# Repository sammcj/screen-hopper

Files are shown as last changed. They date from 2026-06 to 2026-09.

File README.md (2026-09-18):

# Screen Hopper: a smart KVM switch

This is a USB input switcher that lets you use you mouse and keyboard with two computers by just dragging the mouse cursor from one screen to the other. It's like Logitech Flow, Mouse without Borders, Synergy or Apple Universal Control, but it works entirely in hardware. No special software is required on the computers. It works with Windows, Linux and Mac.

Here's a [demo video](https://www.youtube.com/watch?v=z24jG9Nh5gk).

This project is derived from [HID Remapper](https://github.com/jfedor2/hid-remapper) so it inherits all the nice features like input remapping, sensitivity adjustment, polling rate overclocking and more. Check out that project's documentation to see its full potential.

Screen shapes and their relative position are configurable [through a web browser](https://www.jfedor.org/screen-hopper-config/) using WebHID (Chrome or Chrome-based browser required).

In addition to dragging the cursor from one screen to the other, you can also map a key or button to switch between screens.

Wireless receivers are supported and multiple devices can be connected at the same time using a USB hub.

## Profiles

Pico A stores up to 4 independent profiles. Each profile has its own screens, mappings, sensitivity, edge-resistance and jiggler interval - nothing is shared - so you can switch between, say, a single-monitor layout and a multi-monitor layout without re-running the configuration tool. Profiles are managed from the web tool (Profile tabs + active-profile selector) or directly in the multi-profile JSON shape (`{ "version": 8, "active_profile": 0, "profiles": [...] }`).

Bind any key or button to one of these target usages to switch profiles live:

- `0xfff30000` - cycle to the next profile
- `0xfff30001` .. `0xfff30004` - jump directly to profile 1..4

The hotkey lives inside each profile's own mappings, so include it in every profile you want to be able to leave.

## Keep-awake jiggler

Set a profile's `jiggle_interval` (seconds) to have Pico A nudge whichever machine has been idle longest, stopping the inactive side from locking while you work on the other. Idleness is tracked per output, so using one machine doesn't reset the other's clock.

Bind any source to target usage `0xfff30010` for a runtime on/off toggle - the onboard LED blinks **3 times for ON, 5 times for OFF**. The toggle does not change the persisted interval; it only enables/disables the jiggler for the current power cycle. When the toggle turns the jiggler ON, the cursor on the forwarder machine does a brief down/up/right/left sweep (~250 px each way, returning to where it started) so you can see the toggle landed without looking at the LED.

## Pointer upsampling (experimental)

A 125 Hz mouse (MX Master and similar) hands Pico A one position every 8 ms while the local Mac polls at 1 kHz. With no button held, Pico A walks each new sample out linearly over the following 8 ms in 1 ms steps, so the host sees ~1 kHz updates instead of 8 ms hops. This trades one sample interval of pointer latency for a smoother cursor on 60 Hz displays. Local machine only; drags and everything relative are untouched. On by default. Bind a source to `0xfff30011` to toggle it at runtime (3 blinks on, 5 off). Not persisted.

## Type text from the clipboard

`config-tool/type_text.py` ships a small CLI that turns text on the Pico-A computer into keystrokes on the forwarder machine, useful for passing a URL, a code snippet or a short password across without needing networking or host software on the second computer.

```shell
pbpaste | python3 config-tool/type_text.py    # macOS clipboard
python3 config-tool/type_text.py < file.txt   # from a file
python3 config-tool/type_text.py              # falls back to pbpaste on macOS
```

To fire it from anywhere with a hotkey, bind a shortcut in a tool like BetterTouchTool to
an "Execute Shell Script" action running `pbpaste | python3 config-tool/type_text.py`. Use
absolute paths (the script's Python and `pbpaste`), because such tools run scripts in a
minimal shell without your normal `PATH`, and pipe `pbpaste` in explicitly rather than
relying on the clipboard fallback.

The text is buffered on Pico A (cap: 4096 bytes - longer input is truncated) and replayed at ~70 characters/second through the forwarder's USB HID keyboard interface. Bytes outside printable US-ASCII (plus tab and newline) are dropped by the firmware, so the CLI transliterates non-ASCII first: box drawing becomes `+-|`, smart quotes and dashes become their ASCII forms, accents are stripped (`café` -> `cafe`), symbols get spelled out (`©` -> `(c)`, `½` -> `1/2`, `⌘` -> `cmd`), and ANSI colour escapes plus stray control bytes are removed. Characters with no ASCII form at all (emoji, CJK, Greek) are dropped and listed as a warning. Pass `--raw` to send the bytes untouched; anything still unsupported is listed and the CLI exits unless you pass `--force`. The remote machine must be on a US keyboard layout for punctuation to land correctly; letters and digits are layout-independent.

Screen hopper dual Pico version

## How is it possible?

As you might know, normal mice only send relative inputs (X/Y deltas) to the computer, they don't know where the cursor is on the screen. Screen Hopper needs to know this to be able to switch between the screens. So what it does is it keeps an internal state of where the cursor is based on the inputs received from the mouse and it sends the absolute X/Y position to the connected computers. It is a standard feature of the USB HID protocol, but normally it's only used by devices like touchscreens and graphic tablets.

There are some consequences to this mode of operation, for example the aspect ratios of the screens used need to be configured for Screen Hopper to be able to properly scale the horizontal and vertical inputs. Also it probably won't work very well with games that expect raw mouse inputs.

## How to make the device

There are two hardware versions of the Screen Hopper: the dual Pico version and the triple Pico version. They have the same functionality, but the triple Pico version has better device compatibility - some input devices work with either, but some will only work with the triple Pico version.

See [HARDWARE.md](HARDWARE.md) for details on how to make both versions of the device.

## How to use the configuration tool

A live version of the web configuration tool can be found [here](https://www.jfedor.org/screen-hopper-config/). It only works in Chrome and Chrome-based browsers. On Linux you might need to give yourself permissions to the appropriate `/dev/hidraw*` device. The configuration tool should be used on the computer connected to the Pico running `screenhopper.uf2` or `screenhopper_a.uf2`.

Some of the configuration options are inherited from [HID Remapper](https://github.com/jfedor2/hid-remapper) so check that project for the meaning of those settings (the mapping functionality can do really awesome things!).

Screen Hopper needs to know the screen shapes and their relative position to be able to move the cursor between the two computers. You configure that by entering the position (X, Y) and dimensions (width, height) of each screen. (A graphical preview would be nice here, but for now it's just numbers.) The dimensions use abstract units so their absolute values don't mean much, but you will find some combinations give you reasonable mouse sensitivity. You can adjust the sensitivity for each screen separately.

The "Restrict cursor" setting determines what should happen when you drag the mouse cursor outside of the screens (to the area that's not visible). If you select the "to screens" option, it will not be possible to go outside the visible area. If you select the "to bounding box" option, the cursor will be restricted to the smallest rectangle that covers both screens (this only makes a difference if the touching edges of the two screens are not the same length). If you select "don't restrict", the cursor will not stop at any of the screen edges.

Screens configuration

Depending on the screens configuration and the "Restrict cursor" setting, it might be possible for the cursor to be outside of the visible area. There's a separate setting for mouse sensitivity for that situation.

If you configure the screens so that they don't touch each other (there's a gap) and select the "restrict to screens" option then it will not be possible to drag the cursor from one screen to the other. You can still switch between the screens by mapping some key or button to "Switch screen".

If you can't use the browser-based configuration tool, there's also a [command-line tool](config-tool) that takes JSON in the same format as the web tool on standard input. I only tested it on Linux, but in theory it should also run on Windows and Mac.

## How to compile the firmware

Both Raspberry Pi Pico (RP2040) and Pico 2 (RP2350) are supported.

```shell
git clone https://github.com/jfedor2/screen-hopper.git
cd screen-hopper/firmware

# for pico v1:
make pico1

# for pico v2:
make pico2
```

### Firmware output

After building, the UF2 firmware files are copied to `firmware/pico1/` or `firmware/pico2/`:

| File | Version | Purpose |
| --- | --- | --- |
| `screenhopper.uf2` | Dual | Main Pico (with PIO-USB) |
| `forwarder.uf2` | Dual | Second Pico |
| `screenhopper_a.uf2` | Triple  | Pico A |
| `screenhopper_b.uf2` | Triple  | Pico B (USB host) |

To flash, hold BOOTSEL while plugging in the Pico, then copy the appropriate UF2 file to the drive that appears. Alternatively, `make flash TARGET=<a|b|forwarder|single> [BOARD=pico1|pico2] [CONFIG=path]` wraps the whole thing - it builds (re-baking if `CONFIG=` is given), auto-detects the BOOTSEL volume and uses `picotool load -x` to flash and reboot, or falls back to a Raspberry Pi Debug Probe over SWD when no BOOTSEL device is present.

### Applying config changes without reflashing

For config-only edits (screens, mappings, profiles, jiggler interval, edge resistance) reach for `make apply-config CONFIG=path/to/config.json` instead of `make flash`. It pushes the JSON to the running Pico A over USB HID (live + persisted, no reboot) and also re-bakes `firmware/src/baked_config.h` so the next `make flash` carries the same default. Only Pico A holds screen/mapping config, so config changes never need Pico B or the forwarder reflashed. Verify what the firmware is actually running with `make get-config`.

### Baking a config into the firmware

Flashing a Pico does NOT erase the persisted config sector (it lives outside the UF2 image), but if a board has no persisted config yet, the firmware uses its baked default. Bake one in as a compile-time default by passing `CONFIG` to the build:

```shell
make pico2 CONFIG=../config-tool/config.json
```

The build runs `config-tool/bake_config.py`, which turns the JSON into the same flash-sector image the device would persist, and embeds it in `firmware/src/baked_config.h`. On boot, a config persisted over USB still wins; the baked config is the fallback used when flash holds none (so a freshly flashed board comes up configured without running the configuration tool). The JSON can be a legacy single-profile shape or the multi-profile shape (`{ "version": 8, "active_profile": 0, "profiles": [...] }`).

`CONFIG` is sticky: once baked, plain `make pico2` keeps it across rebuilds. To clear it, build with an empty value, `make bake CONFIG=`. The generated `firmware/src/baked_config.h` is gitignored, so a baked personal config is never committed. A build with no baked config uses the firmware's built-in defaults as before.

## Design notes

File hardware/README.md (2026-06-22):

# Screen Hopper - triple Pico 2 carrier PCB

A carrier board for the triple-Pico version of Screen Hopper. The three Raspberry Pi Pico 2 boards, a high-speed optocoupler, the two resistors, a bypass capacitor and a USB-A host port all mount on one PCB, replacing the breadboard and jumper wires described in [HARDWARE.md](../HARDWARE.md).

Four variants are provided from the same netlist:

| Variant | Folder | Size | Assembly |
| --- | --- | ---- | --- |
| Compact SMD | [`smd/`](smd/) | 92 x 82 mm | Optocoupler + passives reflowed by the fab; you mount the three Picos flat, single-sided |
| Through-hole | [`tht/`](tht/) | 112 x 106 mm | You solder everything; Picos A and Forwarder on headers |
| Double-sided | [`compact/`](compact/) | 81 x 59 mm | Smallest by area. Pico B reflows on the back under Pico A; adds a USB-C host port |
| Plug-in header | [`header/`](header/) | 54 x 60 mm | No Pico reflow - all three Picos plug into 0.1" pin-headers. No host connector (device uses Pico B's micro-USB). Fab places only the opto + 3 passives |

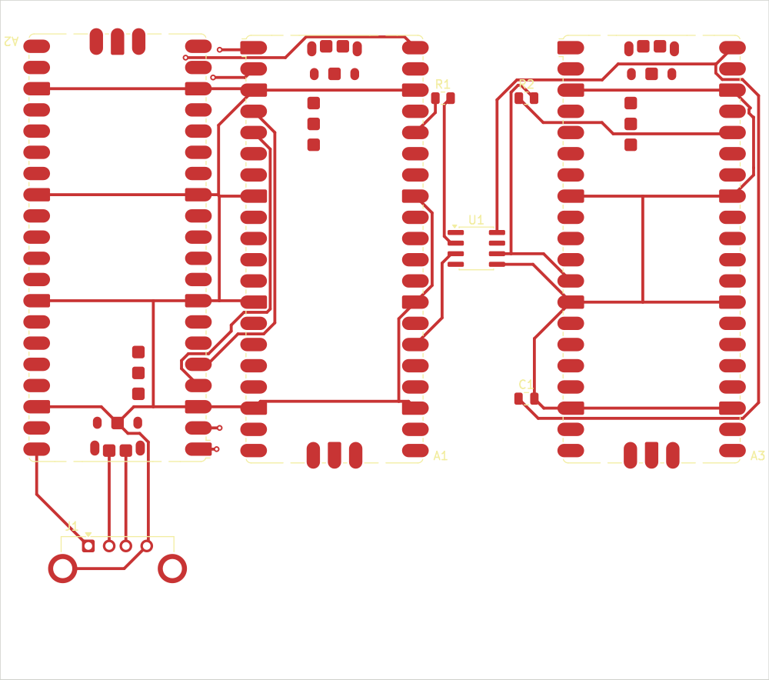
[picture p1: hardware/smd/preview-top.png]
SMD board top view


The double-sided `compact` variant is the smallest board. It stacks Pico B on the back copper directly beneath Pico A and offers both a USB-C and a USB-A host receptacle - **populate only one** (see [Host connector](#host-connector-compact-variant)). It needs the finer JLCPCB 6/6 process (0.2 mm tracks, 0.15 mm clearance, 0.5/0.3 mm vias) to fan out the 0.5 mm-pitch USB-C, where the other two run on the relaxed cheap-everywhere rules.

The `header` variant exists so you never reflow a Pico. All three Picos plug into 0.1" pin-headers (soldering a straight header strip is far easier than reflowing a castellated module), so the fab only places the SMD optocoupler and its three passives. Pico A is on the front top row and Pico B on the back directly behind it; because two through-hole Picos can't share holes, Pico B's hole grid is **offset by 8.89 mm** (half the 17.78 mm row spacing) so the grids interleave. There is no on-board host connector: the mouse/keyboard plugs into Pico B's own micro-USB through an OTG adapter (the same D-/D+/VBUS/GND lines the other variants route to a receptacle), which is what keeps this board small and simple. It uses the same fine 6/6 process as `compact` for the dense interleaved Pico holes. See [Plug-in header variant](#plug-in-header-variant).

## The one thing that matters: galvanic isolation

The optocoupler exists to keep the two host computers electrically isolated. Pico A and Pico B share power and ground fed from computer 1 (and the input device); the Forwarder runs on its own power and ground fed from computer 2. The only connection between the two sides is the optocoupler's internal LED-to-phototransistor light path.

The board enforces this with **two separate ground/power nets** (`GND1`/`VBUS1` and `GND2`/`VBUS2`) and a **copper keepout gap under the optocoupler** that no track or pour may cross. Domain 1 copper stops just left of the opto's input pins; domain 2 copper starts just right of its output pins. Do not bridge the two sides with a wire, a ground pour, or a mounting screw/standoff that ties the grounds together - that defeats the isolation and can create a ground loop between two separate computers.

## What to send to the PCB fab

For a **bare board** (any variant), upload the gerber zip:

- `smd/screen-hopper-smd-gerbers.zip`, `tht/screen-hopper-tht-gerbers.zip`, `compact/screen-hopper-compact-gerbers.zip` or `header/screen-hopper-header-gerbers.zip`

Fab settings: **2 layers, 1.6 mm FR-4, 1 oz copper, HASL or ENIG**. The `smd`/`tht` boards use 0.35 mm tracks, 0.2 mm clearance and 0.35 mm drills, which every fab (PCBWay, JLCPCB, etc.) handles at the cheapest tier. The `compact` board needs 0.2 mm tracks, 0.15 mm clearance and 0.3 mm drills to escape the USB-C, and the `header` board uses the same finer rules to route between its dense interleaved Pico holes - order both from **JLCPCB** (its standard 6/6 process and cheapest tier cover this).

For an **SMD board assembled** by the fab, also supply:

- `BOM-smd.csv`, `BOM-compact.csv` or `BOM-header.csv` - bill of materials
- the matching `-positions.csv` - centroid / pick-and-place file

The fab can place the optocoupler (SOIC-8), the 0805 resistors and the 0805 capacitor (and, on `compact`/`header`, the SMD USB-C receptacle, the two CC resistors and the SOT-23-6 ESD array). The three Pico 2 modules are not standard catalogue parts, so either hand-solder them onto the castellated pads yourself or consign them to the fab. On `smd`/`tht` the USB-A receptacle is a through-hole vertical part, hand-soldered. On `compact` the USB-A is a horizontal edge-mount part with SMD contacts the fab can place plus two through-hole shield posts you solder by hand for mechanical strength. The `compact` board places parts on **both sides** - tell the fab it is a double-sided assembly (Pico B is the only part on the back). On `header` the fab places only the four front-side SMD parts (opto, two resistors, bypass cap); the three Picos are 0.1" through-hole parts you fit yourself, flagged DNP in the Rev0 BOM. There is no host connector - the device plugs into Pico B's micro-USB.

## Bill of materials

See [`BOM-smd.csv`](BOM-smd.csv), [`BOM-tht.csv`](BOM-tht.csv), [`BOM-compact.csv`](BOM-compact.csv) and [`BOM-header.csv`](BOM-header.csv). Summary:

| Ref | Part | SMD | THT | Compact | Header |
| --- | ---- | --- | --- | --- | --- |
| A1, A2, A3 | Raspberry Pi Pico 2 (x3) | flat castellated mount | A/Fwd on headers, B flat | flat; B on the back under A | all on 0.1" headers; B on the back, grid offset 8.89 mm |
| U1 | High-speed optocoupler | HCPL-0601 (SO-8) | 6N137 (DIP-8 + socket) | HCPL-0601 (SO-8) | HCPL-0601 (SO-8) |
| R1 | 470 R (opto LED limit) | 0805 | axial 1/4 W | 0805 | 0805 |
| R2 | 680 R (opto VO pull-up) | 0805 | axial 1/4 W | 0805 | 0805 |
| R3, R4 | 56 k (USB-C CC pull-ups) | - | - | 0805 | - |
| C1 | 100 nF (opto bypass) | 0805 | ceramic disc | 0805 | 0805 |
| J1 | USB-A receptacle (host) | through-hole (vertical) | through-hole (vertical) | horizontal edge-mount (SMD + posts) | - |
| J2 | USB-C receptacle (host) | - | - | SMD 16-pin | - |
| U2 | USBLC6-2SC6 USB ESD array | - | - | SOT-23-6 | - |

Suggested MPNs in the CSVs are starting points - confirm against your supplier's stock.

U1 note: the **6N137 has no true SO-8 package** - its surface-mount form is a wide gull-wing DIP (~10 mm span, 2.54 mm pitch) that does not fit an SO-8 land. The SO-8 builds (smd, compact, header) use the **HCPL-0601** (Broadcom; same family, identical pinout, true SO-8; HCPL-0611 is a higher-CMR drop-in). Only the through-hole build uses a real 6N137, in a DIP-8 socket.

### Host connector (compact variant)

The `compact` board carries **both** a USB-A (`J1`) and a USB-C (`J2`) host receptacle, both horizontal edge-mount parts whose openings face the left board edge, wired to the same D+/D- lines on Pico B's native USB. **Populate and use only one** - they share the data lines, so fitting both and plugging a device into each shorts two devices together. The USB-C port is wired as a host (downstream-facing): `R3`/`R4` (56 k) pull CC1/CC2 up to VBUS to advertise default USB power to whatever plugs in. Leave `R3`/`R4` and `J2` unpopulated if you only want USB-A, or leave `J1` off if you only want USB-C.

Both connectors are commonly-stocked cheap parts: the USB-C is the HRO TYPE-C-31-M-12 (LCSC C165948, a JLCPCB basic part), and the USB-A is a standard horizontal Type-A edge-mount (TE 292303-7 footprint; any equivalent fits the same pads). KiCad 10 ships no 3D model for the exact HRO USB-C footprint, so `J2`'s model is remapped in `build_board.py` to a near-identical 16-pin USB-C (`USB_C_Receptacle_GCT_USB4105...`) purely so the 3D viewer shows a body - the pads, gerbers and pick-and-place still come from the real HRO footprint.

### Plug-in header variant

The `header` board replaces every Pico's flat castellated footprint with a pair of 1x20 0.1" through-hole headers, so you solder a straight pin-header strip (easy) instead of reflowing a 40-pad castellated module (hard). Two things make the layout work:

- **Two-row stack, back-side Pico B.** Pico A sits on the front top row, the Forwarder on the front bottom row, and Pico B on the **back** directly behind Pico A. Two through-hole Picos cannot share holes, so Pico B's hole grid is shifted **8.89 mm** (half the 17.78 mm inter-row spacing) along the board so the two grids interleave - the nearest drilled holes of A and B clear each other by ~7.9 mm. The board is 54 x 60 mm.
- **No host connector.** The mouse/keyboard plugs into **Pico B's own micro-USB** (through a micro-USB OTG / host adapter). Pico B is the USB host; its native USB (D-/D+/VBUS/GND) is on that connector, electrically the same lines the `smd`/`tht`/`compact` boards route out to a USB-A/USB-C receptacle. Dropping the on-board receptacle (and the CC pull-ups, ESD array and USB tap header it needed) is what makes this the simplest, smallest variant. Trade-off: Pico B's micro-USB is also its BOOTSEL/flashing port, so unplug the input device when you reflash Pico B.

**Mounting the Picos - Pico B must sit in a socket.** Pico B (`A2`, on the back, stacked behind Pico A) is the one part that *requires* a female 0.1" socket strip (`SKT1` in the BOM, 2 x 1x20). Solder the socket into A2's hole rows from the back and clip its tails flush on the front; Pico B's own pins then plug into the socket body and never pass through the board. This is necessary because Pico A's pins, soldered on the front, protrude ~4.4 mm out the back (6 mm pins through a 1.6 mm board) directly under Pico B's body - the socket lifts Pico B ~8.5 mm clear so A's through-pins stop ~4 mm short of it (and the two pin grids interleave 8.89 mm apart, so the pins themselves never line up either). Pico A and the Forwarder sit on the front with nothing stacked over them, so they may be soldered to plain male pin-headers or socketed for easy swapping - your choice. The PCB is identical either way: a socket reuses the same plated holes, so it has no separate footprint (which is why it does not appear in the 3D render).

Silkscreen on the board names each Pico (Pico A / Pico B (back) / Forwarder), prints the corner pin numbers (1/20/21/40) for each Pico, and carries a one-line signal legend (A<->B serial on GP0-3, opto on A.GP20 / Fwd.GP9, host = Pico B micro-USB).

The fab populates only the four SMD parts (`U1`, `R1`, `R2`, `C1`); the three Picos are flagged DNP in [`header/Rev0_BOM-screen-hopper-header.csv`](header/Rev0_BOM-screen-hopper-header.csv) since you fit them by hand. Every populated MPN in the Rev0 BOM was confirmed to return itself as an exact in-stock match in NextPCB's catalogue, so the no-review automated matcher sources them without substituting a wrong value. Ground is poured per-domain (`GND1` on the host side, `GND2` on the Forwarder side) and floods stop short of the isolation gap; a few inner GND pins the autorouter leaves stranded are tied in with explicit stitch tracks, so the board verifies at 0 unconnected.

## Schematic

Each variant ships an editable KiCad schematic alongside its board:

- `smd/screen-hopper-smd.kicad_sch`
- `tht/screen-hopper-tht.kicad_sch`
- `compact/screen-hopper-compact.kicad_sch`

Upload this `.kicad_sch` to tools that ask for one (e.g. Quilter, which uses it to group related components and assign bypass capacitors). It carries the same netlist as the board, so the connectivity matches. A rendered overview is in [`schematic.svg`](schematic.svg).

## Wiring

Authoritative net list:

| Net | Connections |
| --- | --- |
| UART0 (A<->B) | A.GPIO0-B.GPIO1, A.GPIO1-B.GPIO0, A.GPIO2-B.GPIO3, A.GPIO3-B.GPIO2 |
| VBUS1 | A.VBUS, B.VBUS, J1.VBUS (header: no J1 - VBUS1 is just A.VBUS + B.VBUS) |
| GND1 | A.GND, B.GND, J1.GND + shield, B.TP1 (header: just A.GND + B.GND) |
| Opto TX | A.3V3 - R1(470) - U1.2 (anode); U1.3 (cathode) - A.GPIO20 |
| USB host | J1.D- - B.TP2 (USB_DM); J1.D+ - B.TP3 (USB_DP). Header has no on-board host port - the device uses Pico B's own micro-USB |
| ESD (compact only) | U2.I/O1 (pins 1,6) - USB_DP; U2.I/O2 (pins 3,4) - USB_DM; U2.VBUS (5) - VBUS1; U2.GND (2) - GND1 |
| VBUS2 | Fwd.VBUS - U1.8 (VCC) - C1 |
| GND2 | Fwd.GND - U1.5 (GND) - C1 |
| Opto RX | Fwd.3V3 - R2(680) - U1.6 (VO); Fwd.GPIO9 - U1.6 (VO) |

`C1` (100 nF) bypasses the optocoupler's VCC (pin 8) to GND (pin 5) - recommended by the 6N137 datasheet. Optocoupler pin 7 (VE, enable) is left unconnected, matching the working breadboard build (the 6N137's internal pull-down on VE leaves it enabled).

Two deliberate choices, both inherited from the proven breadboard build:

- **`R1` = 470 Ω** sets the opto LED drive to roughly 3.8 mA from the 3.3 V rail. That is slightly below the 6N137's typical 5 mA recommended forward current, but it switches reliably at 1 Mbaud on the breadboard and stays well clear of the LED's 20 mA limit. If you want more margin you can drop to ~330 Ω (about 5.7 mA); leave it at 470 Ω to match the validated design.
- **ESD protection** (`U2`, compact variant only): a USBLC6-2SC6 low-capacitance TVS array sits next to the host connectors and clamps the D+/D- lines to VBUS1/GND1, shunting a static-discharge spike to ground before it reaches Pico B's USB transceiver. It's invisible during normal operation and adds negligible capacitance at full-speed HID rates. It's in domain 1 only and has no effect on the galvanic isolation. The `smd`/`tht` boards omit it (matching the original build); add equivalent protection there yourself if you want it.

## Unplaced board (for external auto-placers)

`make unplaced` writes a board per variant with every footprint loaded and the full netlist assigned, but **no placement and no routing** - the parts are parked in a column just right of an empty board outline:

- `unplaced/screen-hopper-smd-unplaced.kicad_pcb` (95 x 85 mm outline)
- `unplaced/screen-hopper-tht-unplaced.kicad_pcb` (115 x 110 mm outline)
- matching `.kicad_sch` for tools that also want the schematic

Feed one of these to an auto-placement tool, then route it (or let the tool route). Two things the tool won't know about, so check them in the result:

- **Galvanic isolation.** The placer sees `GND1`/`VBUS1` and `GND2`/`VBUS2` as distinct nets but has no reason to keep the two domains physically apart. After placement, confirm domain 2 (the Forwarder `A3`, opto output pins 5/6/8, `C1`, `R2`) sits on one side and everything else on the other, with the optocoupler straddling the boundary and a clear copper gap between - see the isolation section above. The hand-placed boards in `smd/` and `tht/` already do this.
- **Pico B orientation.** Its USB test points (TP1/2/3) must face the USB-A receptacle `J1`.

## Assembly notes

- **Pico B is always SMD-mounted flat**, even on the through-hole board. The USB-A host port wires to Pico B's native USB through its bottom test points (TP1/TP2/TP3 = USB_GND/USB_DM/USB_DP), and only the flat (castellated) footprint exposes those pads.
- **Pico B's micro-USB connector shares the same D+/D- lines as the USB-A port.** Leave Pico B's micro-USB unplugged in normal use - plug it in only to flash Pico B (BOOTSEL).
- **Flashing**: Pico A gets `screenhopper_a.uf2`, Pico B gets `screenhopper_b.uf2`, the Forwarder gets `forwarder.uf2`. Reflash by holding BOOTSEL while connecting that Pico's micro-USB to a computer. Re-upload your config to Pico A afterwards.
- **No ground pour** on `smd`/`tht`/`compact` - ground is routed as copper tracks. For lower EMI you can open the `.kicad_pcb` in KiCad, add a `GND1` zone on the left domain and a `GND2` zone on the right domain (keep them clear of the isolation gap), and refill. The `header` board already pours both domains (the two-row layout strands inner GND pins that pours plus stitch tracks tidy up).
- **No mounting holes** are placed (to avoid accidentally bridging the two ground domains through a metal standoff). Add your own in KiCad if you need them - keep any in the isolation gap non-plated, and don't let a screw or standoff connect domain-1 ground to domain-2 ground.
- **Compact variant is double-sided.** Pico A reflows on the top, Pico B on the back directly beneath it (the only back-side part). Reflow or hand-solder the back first, then the top, or have the fab do both. The USB-C host port (`J2`) and USB-A (`J1`) are mutually exclusive - see [Host connector](#host-connector-compact-variant).

## Regenerating

The boards are generated, routed and verified by scripts in [`lib/`](lib/):

```sh
cd hardware
make all      # build + autoroute + verify + export gerbers for all four variants
make check    # re-run the geometry checks on the built boards
make clean    # delete generated boards and fab files
# or build one: make smd | make tht | make compact | make header
```

Requirements: KiCad 10 (provides the bundled `pcbnew` Python module and `kicad-cli`) and a Java runtime. Download `freerouting.jar` (v2.x, from the freerouting GitHub releases) into `lib/`.

Pipeline: `build_board.py` places the parts and defines the netlist with `pcbnew`, exports a Specctra DSN, the freerouting autorouter routes it, the routes are imported back, and `kicad-cli` exports the gerbers/drill/centroid. `gen_sch.py` then writes the matching `.kicad_sch` and `check_sch.py` verifies its netlist against the same net table.

## Verification

`kicad-cli pcb drc` crashes on this macOS/KiCad 10.0.3 build (a tool bug, reproducible on an empty board), so verification runs through [`lib/check_board.py`](lib/check_board.py), which uses KiCad's own geometry engine to confirm, on every variant:

- **0 unconnected** nets (every pad reaches its net)
- **0 copper-clearance violations** - no different-net copper closer than each variant's design-rule clearance less a 0.02 mm rounding margin (so 0.18 mm for `smd`/`tht` whose rule is 0.2 mm; 0.13 mm for `compact`/`header` whose rule is 0.15 mm)
- **0 copper in the isolation gap** (domains bridged only by the optocoupler)

As a final belt-and-braces step before ordering, open the `.kicad_pcb` in KiCad and run **Inspect > Design Rules Checker** once, and eyeball the board against the wiring table above.

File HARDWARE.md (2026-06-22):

# How to make the device

There are two hardware versions of the Screen Hopper: the dual Pico version and the triple Pico version. They have the same functionality, but the triple Pico version has better device compatibility - some input devices work with either, but some will only work with the triple Pico version.

Both the Raspberry Pi Pico (RP2040) and Raspberry Pi Pico 2 (RP2350) are supported. The pinout and wiring are identical between the two boards. You can mix Pico and Pico 2 boards freely, but each board must be flashed with firmware built for its chip. See the [README](README.md) for build instructions.

The reason for multiple Picos is that we need three USB interfaces and the RP2040/RP2350 chip only has one. In the dual Pico version one of the interfaces is "bit-banged" (implemented in software) using the awesome [Pico-PIO-USB](https://github.com/sekigon-gonnoc/Pico-PIO-USB) library by [sekigon-gonnoc](https://github.com/sekigon-gonnoc).

The Picos talk to one another over serial.

To flash the Picos with the appropriate firmware (see below), hold the BOOTSEL button while connecting the Pico to the computer, then copy the right UF2 file to the "RPI-RP2" drive that shows up. You can find precompiled UF2 files in the [firmware](firmware) folder.

## Dual Pico version

This version is made using:

* two Raspberry Pi Picos (or Pico 2s)
* 6N137 optocoupler
* USB Type A female breakout board (or you could use a USB extender cable cut in half)
* 470 ohm resistor (or similar)
* 680 ohm resistor (or similar)
* breadboard, some jumper wires

Dual Pico version breadboard diagram

The pin connections are as follows.

| `screenhopper.uf2` Pico | USB port breakout |
| --- | --- |
| VBUS | VCC |
| GND | GND |
| GPIO0 | D+ |
| GPIO1 | D- |

| `screenhopper.uf2` Pico | 6N137 optocoupler | |
| --- | --- | --- |
| 3V3 | A | through 470 ohm resistor |
| GPIO20 | C | |

| `forwarder.uf2` Pico | 6N137 optocoupler | |
| --- | --- | --- |
| VBUS | VCC | |
| GND | GND | |
| 3V3 | VO | through 680 ohm resistor |
| GPIO9 | VO | |

## Triple Pico version

This is the version that's compatible with most devices. It's made using:

* three Raspberry Pi Picos (or Pico 2s)
* 6N137 optocoupler
* a USB OTG cable or adapter
* 470 ohm resistor (or similar)
* 680 ohm resistor (or similar)
* breadboard, some jumper wires

Connect your mouse/keyboard to the Pico running `screenhopper_b.uf2` via an OTG cable or adapter, and connect the other two Picos to the two computers.

Triple Pico version breadboard diagram

| `screenhopper_a.uf2` Pico | `screenhopper_b.uf2` Pico |
| --- | --- |
| VBUS | VBUS |
| GND | GND |
| GPIO0 | GPIO1 |
| GPIO1 | GPIO0 |
| GPIO2 | GPIO3 |
| GPIO3 | GPIO2 |

| `screenhopper_a.uf2` Pico | 6N137 optocoupler | |
| --- | --- | --- |
| 3V3 | A | through 470 ohm resistor |
| GPIO20 | C | |

| `forwarder.uf2` Pico | 6N137 optocoupler | |
| --- | --- | --- |
| VBUS | VCC | |
| GND | GND | |
| 3V3 | VO | through 680 ohm resistor |
| GPIO9 | VO | |

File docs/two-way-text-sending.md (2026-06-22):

# Two-way text sending (forwarder machine -> main machine)

Design notes for adding the reverse text direction. Today text flows one way only: the
main machine (Pico A) types onto the forwarder machine via `config-tool/type_text.py`.
Sending text back, so the forwarder machine can type onto the main machine, is possible
but needs a hardware change. This file records what that would take so it can be picked
up later.

## Why it doesn't work today

The Pico A to forwarder link is a single optocoupler, and an optocoupler only passes
signal one way (LED to transistor). Pico A drives the opto LED from `GPIO20` (UART1 TX)
and the forwarder reads the opto transistor on `GPIO9` (UART1 RX). Pico A only ever
configures TX on UART1 (`forwarder_serial_init` in `remapper.cc`) and the forwarder only
configures RX (`forwarder_serial_init` in `forwarder.cc`). There is no electrical path
from the forwarder back to Pico A.

The Pico A to Pico B link (`serial.cc`, UART0) is full-duplex, but Pico B is the USB host
wired to the mouse and keyboard and has no connection to the second machine, so it can't
carry anything from the forwarder side.

So the reverse direction is blocked in hardware, not firmware. No firmware-only workaround
exists, because the one optocoupler physically cannot carry data the other way.

## What it would take

### 1. Hardware: a second optocoupler (the real blocker)

Add a second optocoupler (same HCPL-0601 on the SMD variants, 6N137 on through-hole) plus
its pull-up resistor, wired the opposite way:

- A forwarder TX GPIO (for example `GPIO8`, UART1 TX) drives the new opto's LED.
- Pico A reads the new opto's transistor on a free RX-capable pin (for example `GPIO21`,
  UART1 RX), giving Pico A a full-duplex UART1 (TX on 20, RX on 21).

This keeps the galvanic isolation that is the whole reason the link is optical (see
`hardware/README.md`, "The one thing that matters"). A bare wire between the two ground
domains would defeat the isolation. The current assembled board has no spare opto
footprint, so this is a hand-wired add-on now, or a footprint in the next board revision.

### 2. Firmware

- Forwarder (`forwarder.cc`): it is a USB device on the second machine, so that machine
  pushes text to it via a HID feature or output report. Fill in `tud_hid_set_report_cb`
  (currently empty) to accept a `TYPE_TEXT`-style report, buffer it, and `serial_write()`
  it over the new reverse UART. Add a TX pin to `forwarder_serial_init` (it inits RX only
  today). `serial_write()` already exists and is direction-agnostic.
- Pico A (`remapper.cc`): init UART1 RX, `serial_read()` the reverse channel, buffer into
  a second `type_buffer`, and replay as keyboard reports to a local screen (`output == 0`).
  This mirrors the existing `service_type_text()`, which targets `find_forwarder_screen()`;
  the reverse version targets `find_local_screen()`. The keyboard-to-main-machine path
  already exists from normal operation.

### 3. Host script on the forwarder machine

A mirror of `type_text.py` that grabs the second machine's clipboard and sends it to the
forwarder over USB HID, using the same chunked `TYPE_TEXT` framing (`send_chunk` in
`type_text.py`), pointed at the forwarder's VID/PID.

## Scope and effort

The firmware and host-script work is modest and reuses the existing SLIP/CRC framing and
the type-buffer replay state machine. The gating item is the second optocoupler: until the
reverse opto is wired in, the firmware and script have nothing to carry data over.

## Alternative if it doesn't have to go through the KVM

If the goal is just getting the second machine's clipboard onto the main machine, and it
doesn't have to traverse the hardware, a network path (or a shared file/note) is far less
work than a second optocoupler plus two firmware changes. The opto path only makes sense
if the second machine is deliberately isolated and routing through the hardware is the
point.

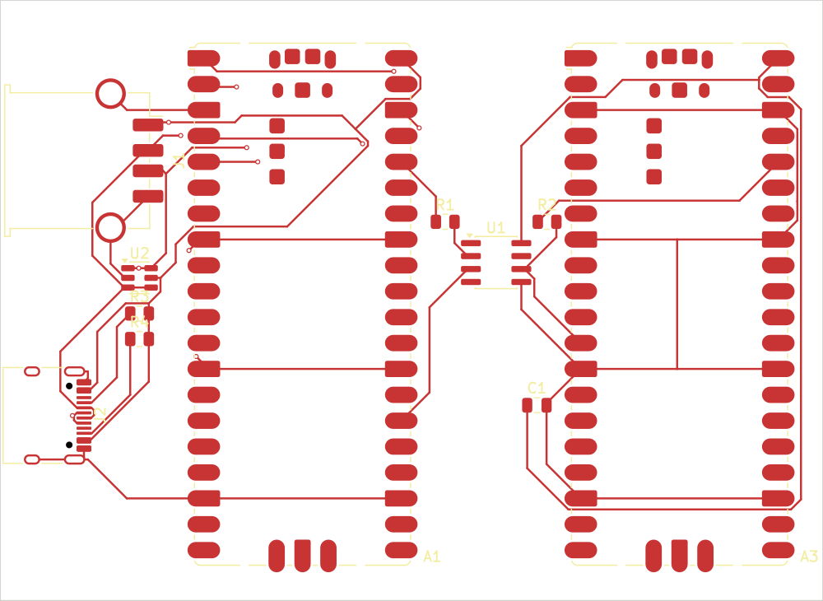
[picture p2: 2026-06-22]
hardware/compact/preview-top.png

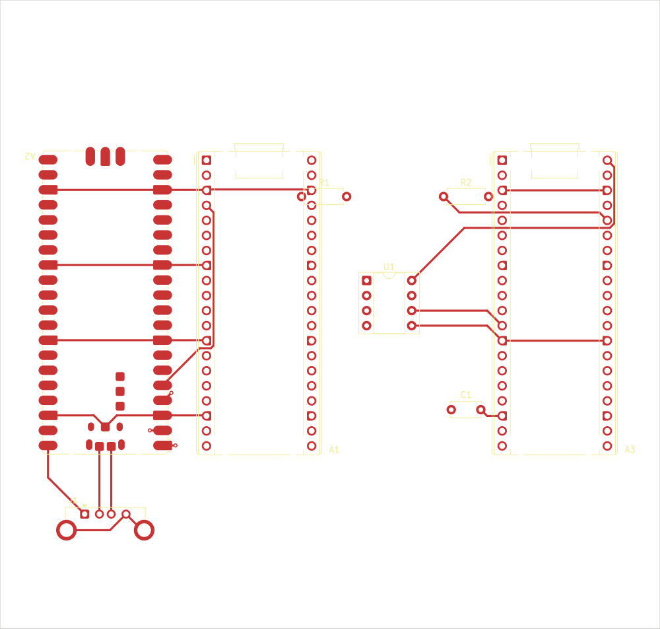
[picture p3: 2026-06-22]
hardware/tht/preview-top.png

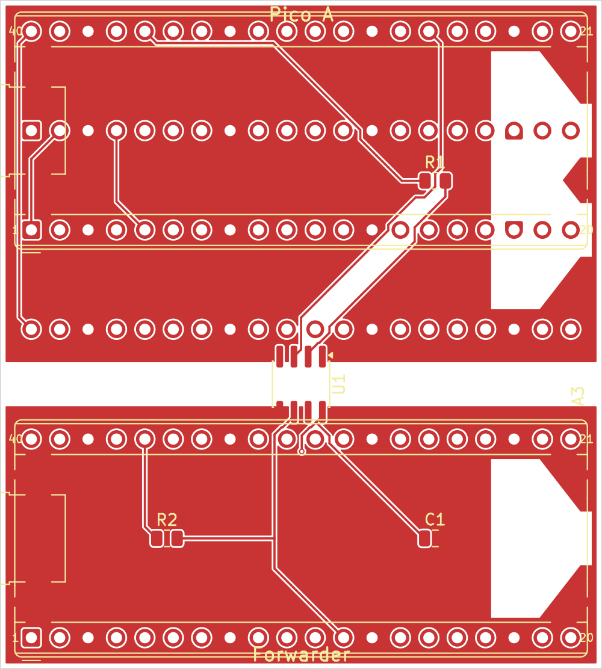
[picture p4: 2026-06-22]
hardware/header/preview-top.png

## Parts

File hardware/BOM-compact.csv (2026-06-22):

Reference | Qty | Value | Package | Description | Suggested MPN | Assembly | Notes
A1 | 1 | RP2350_PicoA | RaspberryPi_Pico_SMD | Raspberry Pi Pico 2 (USB device to computer 1) | Raspberry Pi Pico 2 MODULE (Pi SC1631) - NOT the bare RP2350 chip | consign - NextPCB does not stock the Pico 2 module | Castellated flat to TOP of board. Do NOT let the matcher substitute a bare RP2350A/B QFN chip - it will not fit this module footprint. Turnkey needs a bare-RP2350 redesign (open decision).
A2 | 1 | RP2350_PicoB | RaspberryPi_Pico_SMD | Raspberry Pi Pico 2 (USB host for mouse/keyboard) | Raspberry Pi Pico 2 MODULE (Pi SC1631) - NOT the bare RP2350 chip | consign - NextPCB does not stock the Pico 2 module | Mounts on BACK directly under A1; USB test points TP1-3 used. Same chip-substitution caveat as A1.
A3 | 1 | RP2350_Fwd | RaspberryPi_Pico_SMD | Raspberry Pi Pico 2 (forwarder to computer 2) | Raspberry Pi Pico 2 MODULE (Pi SC1631) - NOT the bare RP2350 chip | consign - NextPCB does not stock the Pico 2 module | Isolated domain 2. Same chip-substitution caveat as A1.
U1 | 1 | HCPL-0601 | SOIC-8 | High-speed 10 Mbit SO-8 optocoupler (galvanic isolation) | HCPL-0601 (Broadcom; true SO-8; NextPCB in stock) | NextPCB SMT | The 6N137 is NOT available in SO-8 (DIP-8 / wide gull-wing only) - do NOT substitute it. HCPL-0611 = pin-compatible higher-CMR alternative.
R1 | 1 | 470R | R_0805_2012Metric | Resistor 470 ohm 1/8W (opto LED current limit) | RC0805JR-07470RL (Yageo 0805 5%; NextPCB in stock) | NextPCB SMT | Domain 1
R2 | 1 | 680R | R_0805_2012Metric | Resistor 680 ohm 1/8W (opto VO pull-up) | RC0805FR-07680RL (Yageo 0805 1%; NextPCB in stock) | NextPCB SMT | Domain 2 - replaces the 7-18 day KOA RK73B2ATTD681J
R3 | 1 | 56k | R_0805_2012Metric | Resistor 56k 0805 (USB-C CC1 pull-up Rp) | AC0805FR-0756KL (Yageo 0805 1%; NextPCB in stock) | NextPCB SMT | Domain 1; CC pull-up Rp - value non-critical (+/-20% per USB spec); any 56k 0805 OK
R4 | 1 | 56k | R_0805_2012Metric | Resistor 56k 0805 (USB-C CC2 pull-up Rp) | AC0805FR-0756KL (Yageo 0805 1%; NextPCB in stock) | NextPCB SMT | Domain 1; CC pull-up Rp - value non-critical (+/-20% per USB spec); any 56k 0805 OK
C1 | 1 | 100nF | C_0805_2012Metric | Capacitor 100nF X7R 16V+ (opto VCC bypass) | 100nF 0805 X7R 16V+ (any; let NextPCB basic library pick) | NextPCB SMT | Domain 2; across opto pins 8-5; non-critical decoupling
J1 | 1 | USB_A_Host | USB_A_TE_292303-7_Horizontal | USB Type-A horizontal edge-mount receptacle (mouse/keyboard input) | TE 292303-7 (NextPCB in stock; pricey ~$6) or std horizontal Type-A on same pads | NextPCB SMT (2 THT shield posts - selective/hand solder) | SMD contacts + 2 THT shield posts; alternative to J2 - populate only ONE
J2 | 1 | USB_C_Host | USB_C_Receptacle_HRO_TYPE-C-31-M-12 | USB Type-C 2.0 16-pin receptacle (mouse/keyboard input) | TYPE-C-31-M-12 (HRO; NextPCB in stock) | NextPCB SMT | Pure SMD - preferred for turnkey; alternative to J1 - populate only ONE
U2 | 1 | USBLC6-2SC6 | SOT-23-6 | USB 2.0 ESD / TVS diode array protecting the host port D+/D- | USBLC6-2SC6 (SOT-23-6; NextPCB in stock) | NextPCB SMT | Domain 1; low-capacitance USB-rated clamp near the connectors

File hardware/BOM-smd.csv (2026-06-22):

Reference | Qty | Value | Package | Description | Suggested MPN | Assembly | Notes
A1 | 1 | RP2350_PicoA | RaspberryPi_Pico_SMD | Raspberry Pi Pico 2 (USB device to computer 1) | Raspberry Pi SC1631 | hand-solder / consign | Castellated edge-mount flat to board
A2 | 1 | RP2350_PicoB | RaspberryPi_Pico_SMD | Raspberry Pi Pico 2 (USB host for mouse/keyboard) | Raspberry Pi SC1631 | hand-solder / consign | Must be non-W with castellations; USB test points TP1-3 used
A3 | 1 | RP2350_Fwd | RaspberryPi_Pico_SMD | Raspberry Pi Pico 2 (forwarder to computer 2) | Raspberry Pi SC1631 | hand-solder / consign | Isolated domain 2
U1 | 1 | HCPL-0601 | SOIC-8 | High-speed 10 Mbit SO-8 optocoupler (galvanic isolation) | HCPL-0601 / HCPL-0611 (Broadcom; true SO-8) | PCBWay SMT | SO-8 optocoupler. The 6N137 has no SO-8 package (DIP-8 / gull-wing only) - do NOT substitute it.
R1 | 1 | 470 | R_0805_2012Metric | Resistor 470 ohm 1/8W 1% (opto LED current limit) | generic 0805 470R | PCBWay SMT | Domain 1
R2 | 1 | 680 | R_0805_2012Metric | Resistor 680 ohm 1/8W 1% (opto VO pull-up) | generic 0805 680R | PCBWay SMT | Domain 2
C1 | 1 | 100nF | C_0805_2012Metric | Capacitor 100nF X7R 16V+ (opto VCC bypass) | generic 0805 100nF X7R | PCBWay SMT | Domain 2; across opto pins 8-5
J1 | 1 | USB_A_Host | USB_A_Connfly_DS1095 | USB Type-A receptacle (mouse/keyboard input) | Connfly DS1095-WNPxxx | hand-solder | Through-hole; wired to Pico B native USB

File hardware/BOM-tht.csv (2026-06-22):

Reference | Qty | Value | Package | Description | Suggested MPN | Assembly | Notes
A1 | 1 | RP2350_PicoA | RaspberryPi_Pico_Common_THT | Raspberry Pi Pico 2 (USB device to computer 1) | Raspberry Pi SC1631 | you solder | On 2x20 female headers or soldered direct
A2 | 1 | RP2350_PicoB | RaspberryPi_Pico_SMD | Raspberry Pi Pico 2 (USB host for mouse/keyboard) | Raspberry Pi SC1631 | you solder | Flat SMD-mount required for USB test points TP1-3
A3 | 1 | RP2350_Fwd | RaspberryPi_Pico_Common_THT | Raspberry Pi Pico 2 (forwarder to computer 2) | Raspberry Pi SC1631 | you solder | Isolated domain 2
U1 | 1 | 6N137 | DIP-8 | High-speed optocoupler 10 Mbit (galvanic isolation) | 6N137 | you solder | Use an 8-pin DIP socket (recommended)
XU1 | 1 | DIP-8 socket | DIP-8 socket | 8-pin DIP IC socket for U1 (optional) | generic DIP-8 socket | you solder | Lets you swap the optocoupler
R1 | 1 | 470 | R_Axial_DIN0207 | Resistor 470 ohm 1/4W axial (opto LED current limit) | generic 470R 1/4W | you solder | Domain 1
R2 | 1 | 680 | R_Axial_DIN0207 | Resistor 680 ohm 1/4W axial (opto VO pull-up) | generic 680R 1/4W | you solder | Domain 2
C1 | 1 | 100nF | C_Disc_5mm | Capacitor 100nF ceramic disc 5mm pitch (opto VCC bypass) | generic 100nF disc | you solder | Domain 2; across opto pins 8-5
J1 | 1 | USB_A_Host | USB_A_Connfly_DS1095 | USB Type-A receptacle (mouse/keyboard input) | Connfly DS1095-WNPxxx | you solder | Through-hole; wired to Pico B native USB
H1-H4 | 4 | Header 2x20 | 2.54mm female header | Female headers for Pico A and Forwarder (optional) | generic 1x20 2.54mm | you solder | Two per socketed Pico if you want them removable

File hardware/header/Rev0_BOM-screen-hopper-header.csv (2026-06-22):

Designator* | Quantity* | Manufacturer Part Number* | Manufacturer | Package/Footprint | Description | Procurement Type | Customer Note
A2 | 1 | SC1631 | Raspberry Pi | RaspberryPi_Pico_Common_THT | Raspberry Pi Pico 2 (RP2350) - USB host for mouse/keyboard | DNP | DO NOT POPULATE. User-fitted Pico 2 on the BACK of the board, hole grid offset 8.89mm from A1. The mouse/keyboard plugs into this Pico's own micro-USB (OTG adapter).
A1 | 1 | SC1631 | Raspberry Pi | RaspberryPi_Pico_Common_THT | Raspberry Pi Pico 2 (RP2350) - USB device to computer 1 | DNP | DO NOT POPULATE. User plugs a Pico 2 module into a 0.1" pin-header here. Top row, front.
A3 | 1 | SC1631 | Raspberry Pi | RaspberryPi_Pico_Common_THT | Raspberry Pi Pico 2 (RP2350) - forwarder to computer 2 | DNP | DO NOT POPULATE. User-fitted Pico 2, bottom row. Isolated domain 2.
C1 | 1 | 0805B104K500CT | Walsin | 0805 | Capacitor 100nF X7R 50V (opto VCC decoupling) |  | Non-critical decoupling; any 100nF 0805 X7R OK.
R1 | 1 | WR08X4700FTL | Walsin | 0805 | Resistor 470R 1% (opto LED current limit) |  | HQ# RE0195837. Walsin WR08X4700FTL. Any 470R 0805 acceptable if the matcher prefers another.
R2 | 1 | WR08X6800FTL | Walsin | 0805 | Resistor 680R 1% (opto VO pull-up) |  | Walsin WR08X6800FTL. Any 680R 0805 acceptable if the matcher prefers another.
U1 | 1 | HCPL-0601-500E | Broadcom | SOIC-8 | High-speed 10 Mbit optocoupler, SO-8 (galvanic isolation) |  | HQ# IS0009935. True SO-8 part. The 6N137 is NOT available in SO-8 (DIP-8 or wide gull-wing only) - do NOT substitute it. HCPL-0611 is a pin-compatible higher-CMR alternative in this same SO-8 footprint.

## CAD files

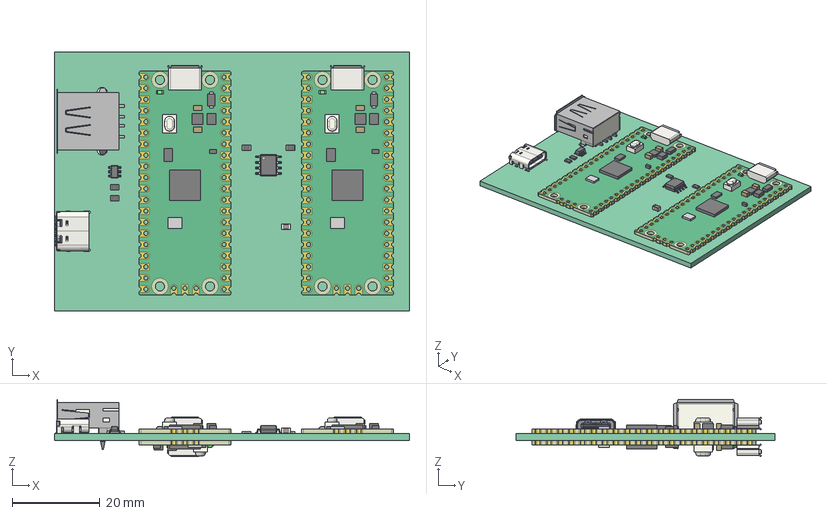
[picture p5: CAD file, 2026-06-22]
hardware/compact/screen-hopper-compact-screen-hopper-compact.step
80.8 x 58.9 x 13.1 mm
Local_CS_296b
Pcb_296b
PCB_Sketch_296b
USB_C_Receptacle_16P_TopMnt_Horizontal_GCT_USB4105-xx-A
USB_C_Receptacle_16P_TopMnt_Horizontal_GCT_USB4105-xx-A001
USB_C_Receptacle_16P_TopMnt_Horizontal_GCT_USB4105-xx-A002
USB_C_Receptacle_16P_TopMnt_Horizontal_GCT_USB4105-xx-A003
USB_C_Receptacle_16P_TopMnt_Horizontal_GCT_USB4105-xx-A004
USB_C_Receptacle_16P_TopMnt_Horizontal_GCT_USB4105-xx-A005
USB_C_Receptacle_16P_TopMnt_Horizontal_GCT_USB4105-xx-A006
USB_C_Receptacle_16P_TopMnt_Horizontal_GCT_USB4105-xx-A007
USB_C_Receptacle_16P_TopMnt_Horizontal_GCT_USB4105-xx-A008
USB_C_Receptacle_16P_TopMnt_Horizontal_GCT_USB4105-xx-A009
USB_C_Receptacle_16P_TopMnt_Horizontal_GCT_USB4105-xx-A010
USB_C_Receptacle_16P_TopMnt_Horizontal_GCT_USB4105-xx-A011
USB_C_Receptacle_16P_TopMnt_Horizontal_GCT_USB4105-xx-A012
USB_C_Receptacle_16P_TopMnt_Horizontal_GCT_USB4105-xx-A013
USB_C_Receptacle_16P_TopMnt_Horizontal_GCT_USB4105-xx-A014
USB_C_Receptacle_16P_TopMnt_Horizontal_GCT_USB4105-xx-A015
USB_C_Receptacle_16P_TopMnt_Horizontal_GCT_USB4105-xx-A016
USB_C_Receptacle_16P_TopMnt_Horizontal_GCT_USB4105-xx-A017
USB_C_Receptacle_16P_TopMnt_Horizontal_GCT_USB4105-xx-A018
USB_C_Receptacle_16P_TopMnt_Horizontal_GCT_USB4105-xx-A019
USB_C_Receptacle_16P_TopMnt_Horizontal_GCT_USB4105-xx-A020
USB_C_Receptacle_16P_TopMnt_Horizontal_GCT_USB4105-xx-A021
USB_C_Receptacle_16P_TopMnt_Horizontal_GCT_USB4105-xx-A022
USB_C_Receptacle_16P_TopMnt_Horizontal_GCT_USB4105-xx-A023
USB_C_Receptacle_16P_TopMnt_Horizontal_GCT_USB4105-xx-A024
USB_C_Receptacle_16P_TopMnt_Horizontal_GCT_USB4105-xx-A025
USB_C_Receptacle_16P_TopMnt_Horizontal_GCT_USB4105-xx-A026
USB_C_Receptacle_16P_TopMnt_Horizontal_GCT_USB4105-xx-A027
USB_C_Receptacle_16P_TopMnt_Horizontal_GCT_USB4105-xx-A028
USB_C_Receptacle_16P_TopMnt_Horizontal_GCT_USB4105-xx-A029
USB_C_Receptacle_16P_TopMnt_Horizontal_GCT_USB4105-xx-A030
USB_C_Receptacle_16P_TopMnt_Horizontal_GCT_USB4105-xx-A031
USB_C_Receptacle_16P_TopMnt_Horizontal_GCT_USB4105-xx-A032
USB_C_Receptacle_16P_TopMnt_Horizontal_GCT_USB4105-xx-A033
USB_C_Receptacle_16P_TopMnt_Horizontal_GCT_USB4105-xx-A034
USB_C_Receptacle_16P_TopMnt_Horizontal_GCT_USB4105-xx-A035
R2_R_0805_2012Metric_fe8d06aba9c3
USB_A_TE_292303-7_Horizontal
USB_A_TE_292303-7_Horizontal001
USB_A_TE_292303-7_Horizontal002
USB_A_TE_292303-7_Horizontal003
C1_C_0805_2012Metric_656b3a97c492
R1_R_0805_2012Metric_6b29dc63a196
RaspberryPi_Pico_Module_KiCad
R4_R_0805_2012Metric_ba096996c26e
U2_SOT-23-6_d4b87cc1bc35
RaspberryPi_Pico_Module_KiCad001
U1_SOIC-8_3.9x4.9mm_P1.27mm_87895ce078d2
R3_R_0805_2012Metric_d5da42002b7f
RaspberryPi_Pico_Module_KiCad002

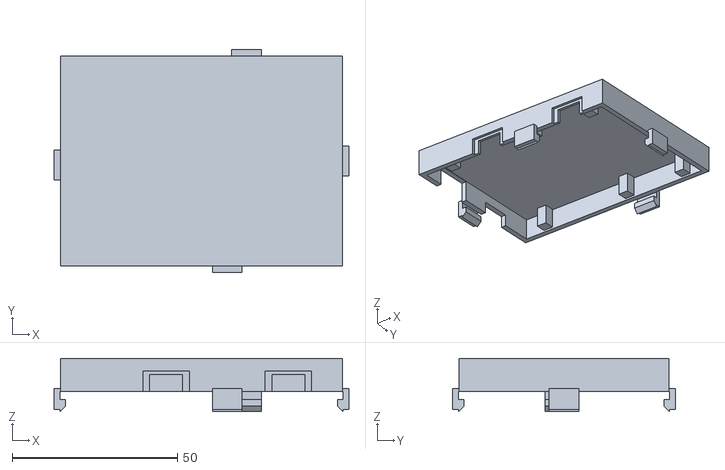
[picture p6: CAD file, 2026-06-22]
hardware/enclosure/screen-hopper-enclosure-lid.stl
89.4 x 67.5 x 16.2

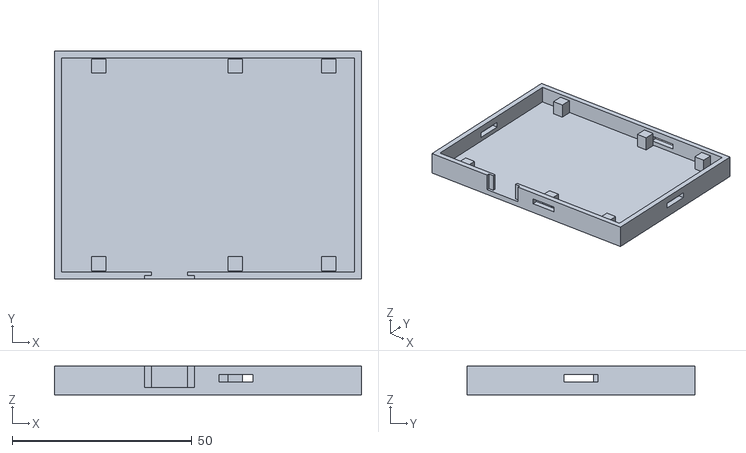
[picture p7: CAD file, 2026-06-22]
hardware/enclosure/screen-hopper-enclosure-base.stl
85.4 x 63.5 x 8.00

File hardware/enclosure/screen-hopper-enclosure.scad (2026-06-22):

// Screen Hopper - two-part 3D-printed enclosure for the "compact" triple-Pico board.
//
// Geometry is taken directly from hardware/compact/screen-hopper-compact.kicad_pcb:
//   board outline 80.77 x 58.94 mm (plain rectangle), 1.6 mm thick, no mounting holes.
//   Connectors (board-local, origin at the board's min corner = kicad (2.31, 0.24)).
//   All three Pico micro-USBs are on the SAME edge (front, Y-min); A2 is mounted on
//   the underside directly beneath A1, so its connector sits below the board on that
//   same front edge (verified against a kicad-cli render of both board sides):
//     A1 micro-USB  front edge (Y-min)  X = 29.69   TOP side    (above board)
//     A2 micro-USB  front edge (Y-min)  X = 29.69   BOTTOM side (below board, under A1)
//     A3 micro-USB  front edge (Y-min)  X = 66.69   TOP side    (above board)
//     J2 USB-C      left  edge (X-min)  Y = 40.76   top side
//     J1 USB-A      left  edge (X-min)  Y = 15.76   top side
//   The Pico USB mouths sit ~2 mm inside the board edge, so cutouts are sized for the
//   plug shell to reach through the wall+recess tunnel.
//
// Because A2 hangs below the board, the board drops into the base vertically. Split is
// at ~board-top: the BASE is a shallow tray that holds the board on risers and carries
// A2's (bottom-side) cutout; the LID is a tall cover carrying the four top-side
// connector cutouts and clamping the board onto the risers. On the front wall the A1
// (lid) and A2 (base) openings stack either side of the seam at X = 29.69.
//
// Render a single part for printing:
//   openscad -D 'part="base"' -o base.stl screen-hopper-enclosure.scad
//   openscad -D 'part="lid"'  -o lid.stl  screen-hopper-enclosure.scad
// part="both" (default) shows the assembly; part="exploded" separates the halves.

part = "both";          // "base" | "lid" | "both" | "exploded"

$fn = 64;
eps = 0.02;

/* ---------------- fit / wall parameters (mm) ---------------- */
clr        = 0.2;       // print fit clearance (snap engagement, lid register)
board_clr  = 0.3;       // XY gap around the PCB inside the cavity
wall       = 2.0;       // side-wall thickness
floor_th   = 2.0;       // base floor thickness
top_th     = 2.0;       // lid top thickness

/* ---------------- board ---------------- */
bw = 80.77;             // board width  (X)
bd = 58.94;             // board depth  (Y)
bth = 1.6;              // board thickness

/* ---------------- vertical stack (Z measured from base outer bottom) ---------------- */
bottom_gap = 5.0;       // PCB bottom above base inner floor - clears A2 underside (~3.6)
top_gap    = 7.5;       // PCB top to lid inner ceiling - clears USB-A shell (6.5) + margin

board_bot = floor_th + bottom_gap;     // 7.0
board_top = board_bot + bth;           // 8.6
seam      = board_top - 0.6;           // 8.0  base-wall top / lid joint
ceil_in   = board_top + top_gap;       // 16.1 lid inner ceiling
outer_h   = ceil_in + top_th;          // 18.1 overall outer height

/* ---------------- XY footprint ---------------- */
cav_w = bw + 2*board_clr;
cav_d = bd + 2*board_clr;
outer_w = cav_w + 2*wall;
outer_d = cav_d + 2*wall;

bx0 = wall + board_clr;     // PCB min corner in part coords (2.3, 2.3)
by0 = wall + board_clr;

/* connector centres in part coords (board-local + board origin) */
A1x = bx0 + (32.00 - 2.31);
A3x = bx0 + (69.00 - 2.31);
A2x = bx0 + (32.00 - 2.31);
J2y = by0 + (41.00 - 0.24);
J1y = by0 + (16.00 - 0.24);

/* connector aperture sizes [width-along-wall], generous so the plug shell clears the
   wall+recess tunnel (mouths are ~2 mm inside the board edge) */
mUSB_w = 10.0;          // micro-USB through-cut (plug nose/shell)
usbc_w = 12.0;          // USB-C
usba_w = 15.0;          // USB-A

/* micro-USB ports are recessed ~2.4 mm behind the board edge. To let the plug seat,
   the front wall is thinned to `thin_wall` over a pocket around each micro-USB cutout,
   giving the overmould a lead-in and the metal plug more reach into the socket. */
thin_wall  = 1.0;
mUSB_pkt_w = 14.0;      // pocket width (overmould lead-in)
mUSB_pkt_h = 8.0;       // pocket height

/* connector Z spans (absolute), open toward the seam so parts assemble vertically */
// A2 (bottom side, base FRONT wall): centre ~ board_bot-2.3=4.7, open up to seam.
A2_z0 = floor_th;  A2_z1 = seam + eps;
// top-side (lid walls): open down to the seam, up to just over each connector top.
mUSB_z1 = 13.2;         // A1/A3 micro-USB top (board_top+1.0 pico +2.6 conn +margin)
usbc_z1 = 12.5;         // USB-C top (board_top + 3.26 + margin)
usba_z1 = 15.9;         // USB-A top (board_top + 6.5 + margin)

/* ---------------- support / clamp posts (bare-FR4 spots, clear top & bottom) ----------------
   board-local XY; risers sit under them (z floor..board_bot), lid ribs above (board_top..ceil). */
post_xy = [[10,2],[48,2],[74,2],[10,57],[48,57],[74,57]];
post = 4.0;             // square post side

/* ---------------- snap clips ----------------
   {face, pos} on connector-free wall spots. Cantilever arm on the lid hooks a window
   in the base wall. */
snap_w   = 9.0;         // clip width
arm_t    = 1.8;         // cantilever arm thickness
barb     = 1.5;         // barb engagement depth
win_z0   = 3.6;         // base window bottom
win_z1   = 5.6;         // base window top (barb hooks under this edge)
arm_gap  = clr;         // gap between arm inner face and base wall outer face

snaps = [
  ["front", (A1x+A3x)/2],
  ["back",  outer_w*0.66],
  ["left",  (J1y+J2y)/2],
  ["right", outer_d/2],
];

/* ==================================================================== */
/* helpers                                                              */
/* ==================================================================== */

// Cut a rectangular aperture through one wall, between z0 and z1.
module wall_cut(face, pos, width, z0, z1) {
  d = wall + 2;  h = z1 - z0;
  if (face == "front")
    translate([pos - width/2, -1,           z0]) cube([width, d, h]);
  else if (face == "back")
    translate([pos - width/2, outer_d-d+1,  z0]) cube([width, d, h]);
  else if (face == "left")
    translate([-1,           pos - width/2, z0]) cube([d, width, h]);
  else if (face == "right")
    translate([outer_w-d+1,  pos - width/2, z0]) cube([d, width, h]);
}

// Thin a wall to `thin_wall` over a pocket (removes the OUTER face material), giving a
// recessed connector port a lead-in. Leaves `thin_wall` of material on the inner side.
module wall_pocket(face, pos, width, z0, z1) {
  rd = wall - thin_wall + 1;  h = z1 - z0;          // outer depth removed (+1 overrun)
  if (face == "front")
    translate([pos - width/2, -1, z0]) cube([width, rd, h]);
  else if (face == "back")
    translate([pos - width/2, outer_d - rd + 1, z0]) cube([width, rd, h]);
  else if (face == "left")
    translate([-1, pos - width/2, z0]) cube([rd, width, h]);
  else if (face == "right")
    translate([outer_w - rd + 1, pos - width/2, z0]) cube([rd, width, h]);
}

/* ==================================================================== */
/* BASE                                                                 */
/* ==================================================================== */
module base() {
  difference() {
    union() {
      // outer shell up to the seam
      cube([outer_w, outer_d, seam]);
    }
    // hollow cavity (above the floor, inside the walls), open at the top
    translate([wall, wall, floor_th])
      cube([cav_w, cav_d, seam - floor_th + eps]);
    // A2 connector aperture (FRONT wall, bottom side, under A1), open to seam so the
    // board drops in. Stacks below A1's lid opening at the same X.
    wall_cut("front", A2x, mUSB_w, A2_z0, A2_z1);
    wall_pocket("front", A2x, mUSB_pkt_w, floor_th, seam);   // recess lead-in for A2
    // snap windows
    for (s = snaps) snap_window(s[0], s[1]);
  }
  // risers the PCB rests on
  for (p = post_xy)
    translate([bx0 + p[0] - post/2, by0 + p[1] - post/2, floor_th])
      cube([post, post, bottom_gap]);
}

// rectangular through-window in the base wall for a snap barb (clearance each side)
module snap_window(face, pos) {
  wall_cut(face, pos, snap_w + 2*clr, win_z0, win_z1);
}
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

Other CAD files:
hardware/compact/screen-hopper-compact-screen-hopper-compact.stl

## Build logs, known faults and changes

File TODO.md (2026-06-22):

# TODO - things I want to implement

- The ability to store macros on the Pico and trigger them with a press.

- Bidirectional clipboard sync. The Pico-A-to-forwarder direction is implemented via `config-tool/type_text.py` (host-side CLI reads the clipboard or stdin and the firmware replays it as USB HID keystrokes through the forwarder, capped at 4 KB, ~70 cps, US-ASCII). The reverse direction (forwarder machine -> Pico A machine) needs either a second optocoupler in the opposite direction (small PCB revision) or a separate host-side relay on the forwarder side; the current single-opto link is one-way only. Full design notes for the reverse direction: [`docs/two-way-text-sending.md`](docs/two-way-text-sending.md).

- File sharing via the Pico. Investigated and parked: would need USB Mass Storage emulation on top of the existing composite HID device, the optocoupler tops out around 100 KB/s, and FAT corruption is likely if both hosts mount the fake drive at once. Not a good fit for this hardware - use a USB stick / AirDrop / Syncthing instead.

- Investigate if there is a way we could somehow share / mirror the display of one of the machines, perhaps something like displaylink style emulation (without the need for special drivers).

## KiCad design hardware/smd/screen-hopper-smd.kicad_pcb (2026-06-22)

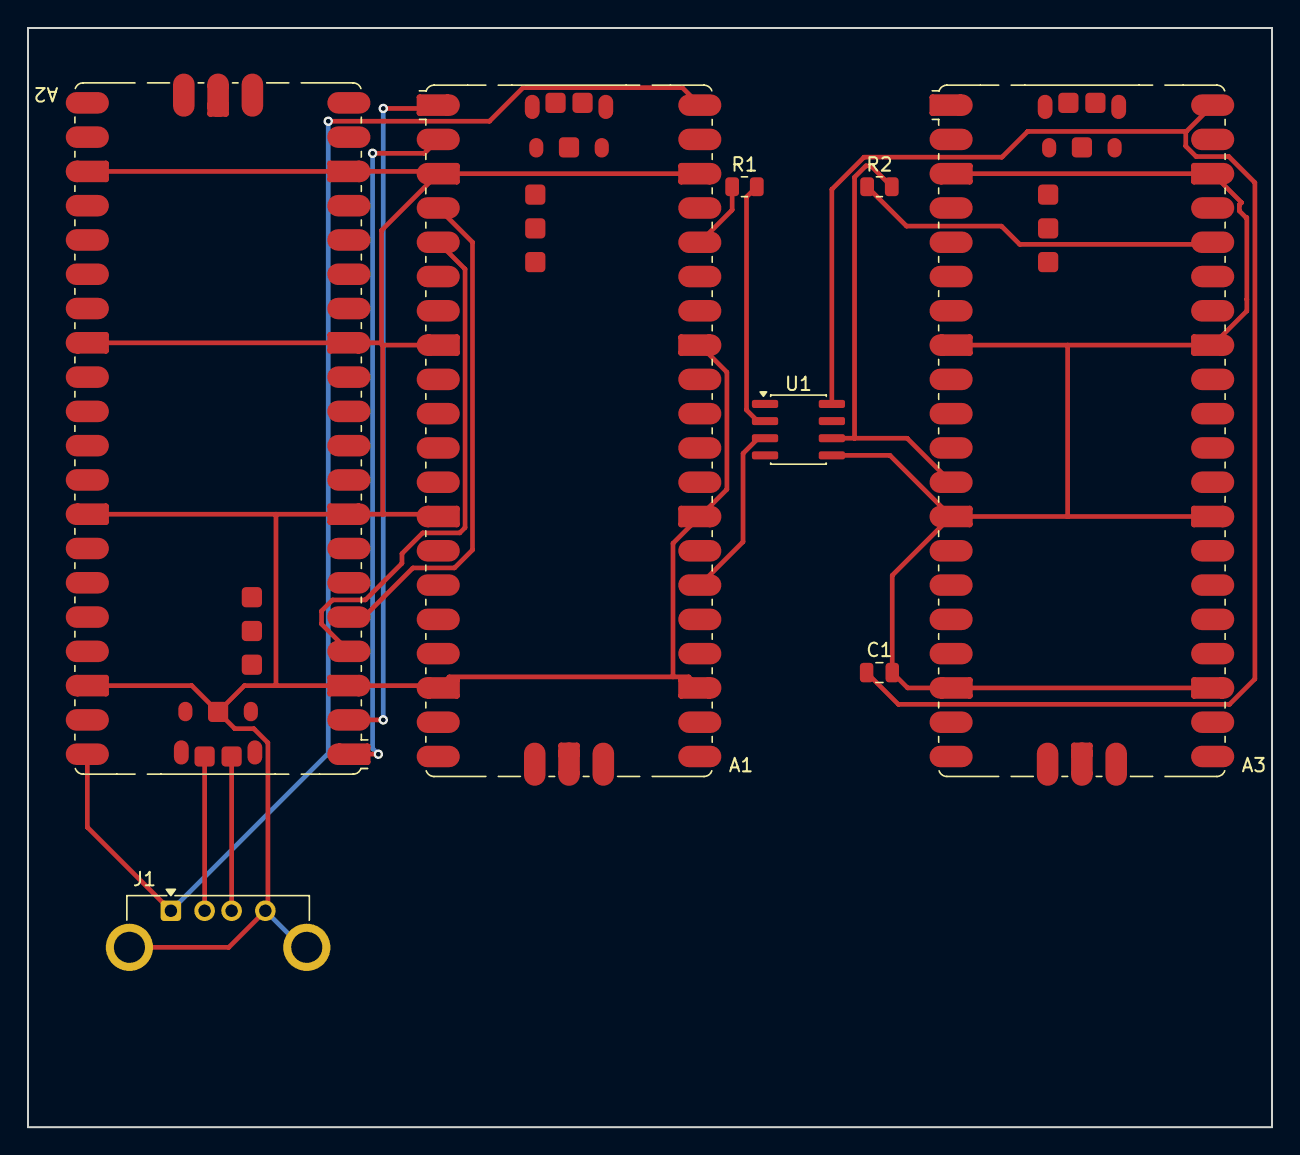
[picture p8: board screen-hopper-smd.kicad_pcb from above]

Board: 2 copper layers, 92.2 x 81.4 mm, 8 parts (0 on the bottom side), 15 nets.

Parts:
A1: RP2350_PicoA; RaspberryPi_Pico_SMD
A2: RP2350_PicoB; RaspberryPi_Pico_SMD
A3: RP2350_Fwd; RaspberryPi_Pico_SMD
C1: 100nF; C_0805_2012Metric
J1: USB_A_Host; USB_A_Connfly_DS1095
R1: 470R; R_0805_2012Metric
R2: 680R; R_0805_2012Metric
U1: HCPL-0601; SOIC-8_3.9x4.9mm_P1.27mm

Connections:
FWD_3V3: A3.36, R2.1
GND1: A1.3, A1.8, A1.13, A1.18, A1.23, A1.28, A1.33, A1.38, A2.3, A2.8, A2.13, A2.18, A2.23, A2.28, A2.33, A2.38, A2.TP1, J1.4, J1.SH
GND2: A3.3, A3.8, A3.13, A3.18, A3.23, A3.28, A3.33, A3.38, C1.2, U1.5
OPTO_3V3: A1.36, R1.1
OPTO_ANODE: R1.2, U1.2
OPTO_CATH: A1.26, U1.3
OPTO_VO: A3.12, R2.2, U1.6
SER_A0_B1: A1.1, A2.2
SER_A1_B0: A1.2, A2.1
SER_A2_B3: A1.4, A2.5
SER_A3_B2: A1.5, A2.4
USB_DM: A2.TP2, J1.2
USB_DP: A2.TP3, J1.3
VBUS1: A1.40, A2.40, J1.1
VBUS2: A3.40, C1.1, U1.8

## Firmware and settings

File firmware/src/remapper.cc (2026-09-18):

#include <set>
#include <unordered_map>
#include <unordered_set>
#include <vector>

#include <bsp/board.h>
#include <tusb.h>

#include "hardware/gpio.h"
#include "hardware/uart.h"
#include "pico/stdio.h"
#include "pico/stdlib.h"

#include "config.h"
#include "crc.h"
#include "descriptor_parser.h"
#include "globals.h"
#include "our_descriptor.h"
#include "remapper.h"
#include "serial.h"

#define FORWARDER_UART uart1
#define FORWARDER_TX_PIN 20

const uint8_t MAPPING_FLAG_STICKY = 0x01;

const uint8_t V_RESOLUTION_BITMASK = (1 << 0);
const uint8_t H_RESOLUTION_BITMASK = (1 << 2);
const uint32_t V_SCROLL_USAGE = 0x00010038;
const uint32_t H_SCROLL_USAGE = 0x000C0238;
const uint32_t MOUSE_X_USAGE = 0x00010030;
const uint32_t MOUSE_Y_USAGE = 0x00010031;
const uint32_t SWITCH_SCREEN_USAGE = 0xFFF20001;

// Profile control usages (vendor-defined). Bind any source key to these
// target_usages via the standard mappings array - same mechanism as
// SWITCH_SCREEN_USAGE.
const uint32_t CYCLE_PROFILE_USAGE = 0xFFF30000;             // next profile (mod profile_count)
const uint32_t ACTIVATE_PROFILE_USAGE_BASE = 0xFFF30001;     // 0xFFF30001..04 activate slots 0..3
const uint32_t TOGGLE_JIGGLE_USAGE = 0xFFF30010;             // flip the jiggler on/off
const uint32_t TOGGLE_ABS_SMOOTH_USAGE = 0xFFF30011;         // flip absolute-position upsampling on/off

const uint8_t NLAYERS = 4;
const uint32_t LAYERS_USAGE_PAGE = 0xFFF10000;

const std::unordered_map<uint32_t, uint8_t> resolution_multiplier_masks = {
    { V_SCROLL_USAGE, V_RESOLUTION_BITMASK },
    { H_SCROLL_USAGE, H_RESOLUTION_BITMASK },
};

std::unordered_map<uint32_t, std::vector<map_source_t>> reverse_mapping;  // target -> sources list

std::unordered_map<uint8_t, std::unordered_map<uint32_t, usage_def_t>> our_usages;  // report_id -> usage -> usage_def
std::unordered_map<uint32_t, usage_def_t> our_usages_flat;

std::vector<uint32_t> layer_triggering_stickies;
std::vector<uint64_t> sticky_usages;  // non-layer triggering, layer << 32 | usage
std::vector<uint64_t> screen_switching_usages;
std::vector<uint64_t> cycle_profile_usages;        // layer << 32 | source_usage
std::vector<uint64_t> toggle_jiggle_usages;        // layer << 32 | source_usage
std::vector<uint64_t> toggle_abs_smooth_usages;    // layer << 32 | source_usage

// Absolute-position upsampling. A 125 Hz mouse delivers one position per 8 ms
// but the host polls us at 1 kHz, so each new sample is walked out over the
// following ABS_SMOOTH_SEGMENT_US in 1 ms steps instead of landing in one hop.
// Costs one sample interval of pointer latency; smooths the 125 Hz -> display
// refresh beat. Only the no-button absolute path is upsampled: drags and
// crossing bursts are relative and stay untouched (their gain model is fit to
// per-flush speed at the mouse's native rate). Runtime toggle, not persisted.
static const uint64_t ABS_SMOOTH_SEGMENT_US = 8000;
static bool abs_smooth_enabled = true;
static int64_t abs_smooth_start_x = 0, abs_smooth_start_y = 0;    // pointer at segment start
static int64_t abs_smooth_target_x = 0, abs_smooth_target_y = 0;  // cursor_x/y being walked to
static uint64_t abs_smooth_t0_us = 0;
static int8_t abs_smooth_screen = -1;
// Each activate-profile entry encodes (layer << 32 | source_usage) plus the
// destination slot index in the low byte of a separate parallel vector.
struct activate_profile_binding_t {
    uint64_t layer_usage;
    uint8_t slot;
};
std::vector<activate_profile_binding_t> activate_profile_usages;

// Profile switches must be deferred: activate_profile() calls
// set_mapping_from_config(), which .assign()s the very vectors the hotkey
// handlers iterate over - that would invalidate the for-loop iterators.
// Instead, the hotkey edge sets pending_profile_switch and the start of the
// next process_mapping() applies it cleanly with the old mappings already
// finished and the new ones ready to take effect on the very next frame.
static int8_t pending_profile_switch = -1;

// Forward declarations: process_mapping() kicks off cursor gestures (the
// jiggler toggle confirmation and the profile-number draw) and cancels the
// local gesture on real mouse input, but the gesture player's state and helpers
// live alongside maybe_jiggle() down near the end of the file.
static void start_jiggle_toggle_gesture(bool enabled);
static void start_profile_number_gesture(uint8_t profile_index);
static void cancel_local_gesture();

// report_id -> ...
uint8_t* reports[MAX_INPUT_REPORT_ID + 1];
uint8_t* prev_reports[MAX_INPUT_REPORT_ID + 1];
uint8_t* report_masks_relative[MAX_INPUT_REPORT_ID + 1];
uint8_t* report_masks_absolute[MAX_INPUT_REPORT_ID + 1];
uint16_t report_sizes[MAX_INPUT_REPORT_ID + 1];

#define OR_BUFSIZE 8
uint8_t outgoing_reports[OR_BUFSIZE][CFG_TUD_HID_EP_BUFSIZE + 2];
uint8_t or_head = 0;
uint8_t or_tail = 0;
uint8_t or_items = 0;

// We need a certain part of mapping processing (absolute->relative mappings) to
// happen exactly once per millisecond. This variable keeps track of whether we
// already did it this time around. It is set to true when we receive
// start-of-frame from USB host.
volatile bool tick_pending;

std::vector<uint8_t> report_ids;

// usage -> ...
std::unordered_map<uint32_t, int32_t> input_state;
std::unordered_map<uint32_t, int32_t> prev_input_state;
std::unordered_map<uint64_t, int32_t> sticky_state;  // layer << 32 | usage -> state
std::unordered_map<uint32_t, int32_t> accumulated;   // * 1000

std::vector<uint32_t> relative_usages;
std::unordered_set<uint32_t> relative_usage_set;

std::unordered_map<uint32_t, int32_t> accumulated_scroll;
std::unordered_map<uint32_t, uint64_t> last_scroll_timestamp;

bool led_state;
uint64_t next_print = 0;
uint32_t reports_received;
uint32_t reports_sent;

// LED feedback state machine for the jiggler-toggle hotkey. While
// blink_transitions_remaining > 0, the main loop drives the onboard LED on a
// fixed cadence (BLINK_INTERVAL_US per transition) and suspends the per-report
// activity flicker so the user sees clear, countable blinks. When done, the
// activity flicker resumes. blink() schedules N pulses (each pulse = LED on
// then off, so N pulses = 2N transitions). 3 pulses signals "jiggler on",
// 5 pulses signals "jiggler off".
static const uint64_t BLINK_INTERVAL_US = 150000;  // 150 ms per LED transition
static const uint8_t BLINK_PULSES_ON = 3;
static const uint8_t BLINK_PULSES_OFF = 5;
uint8_t blink_transitions_remaining = 0;
uint64_t blink_next_transition_us = 0;
bool blink_led_state = false;

static void blink(uint8_t pulses) {
    blink_transitions_remaining = pulses * 2;
    blink_led_state = false;
    blink_next_transition_us = time_us_64();  // fire first transition immediately
}

static void service_blink() {
    if (blink_transitions_remaining == 0) return;
    uint64_t now = time_us_64();
    if (now < blink_next_transition_us) return;
    blink_led_state = !blink_led_state;
    board_led_write(blink_led_state);
    blink_next_transition_us = now + BLINK_INTERVAL_US;
    blink_transitions_remaining--;
    if (blink_transitions_remaining == 0) {
        // Land on LED off so the activity flicker has a known starting point.
        board_led_write(false);
        led_state = false;
    }
}

int64_t cursor_x = 0;
int64_t cursor_y = 0;

// Remember last active local screen for caps lock toggling
int8_t last_local_screen = -1;

int8_t active_screen = 0;

// Per-output timestamp (time_us_64) of the last real keyboard/mouse input from
// Pico B, indexed by the active screen's output (0 = local/USB, 1 = remote/forwarder).
// The keep-awake jiggle fires once the *target* output has been idle for
// jiggle_interval seconds. Tracking per-output means using one machine never
// resets the other's idle timer, so the inactive side keeps getting jiggled
// even while the active side is in use.
uint64_t last_input_per_output_us[2] = { 0, 0 };

// After a drag, hold off repositioning the cursor via the absolute report until
// the user moves again, so the post-drag correction doesn't snap while the hand
// is stationary. Cleared on movement and on any deliberate warp (F8/caps switch).
bool defer_abs_after_drag = false;

int64_t bounds_min_x;
int64_t bounds_max_x;
int64_t bounds_min_y;
int64_t bounds_max_y;

int32_t handle_scroll(uint32_t source_usage, uint32_t target_usage, int32_t movement) {
    int32_t ret = 0;
    if (resolution_multiplier & resolution_multiplier_masks.at(target_usage)) {  // hi-res
        ret = movement;
    } else {  // lo-res
        if (movement != 0) {
            last_scroll_timestamp[source_usage] = time_us_64();
            accumulated_scroll[source_usage] += movement;
            int ticks = accumulated_scroll[source_usage] / (1000 * RESOLUTION_MULTIPLIER);
            accumulated_scroll[source_usage] -= ticks * (1000 * RESOLUTION_MULTIPLIER);
            ret = ticks * 1000;
        } else {
            if ((accumulated_scroll[source_usage] != 0) &&
                (time_us_64() - last_scroll_timestamp[source_usage] > partial_scroll_timeout)) {
                accumulated_scroll[source_usage] = 0;
            }
        }
    }
    return ret;
}

inline int8_t get_bit(const uint8_t* data, int len, uint16_t bitpos) {
    int byte_no = bitpos / 8;
    int bit_no = bitpos % 8;
    if (byte_no < len) {
        return (data[byte_no] & 1 << bit_no) ? 1 : 0;
    }
    return 0;
}

inline uint32_t get_bits(const uint8_t* data, int len, uint16_t bitpos, uint8_t size) {
    uint32_t value = 0;
    for (int i = 0; i < size; i++) {
        value |= get_bit(data, len, bitpos + i) << i;
    }
    return value;
}

inline void put_bit(uint8_t* data, int len, uint16_t bitpos, uint8_t value) {
    int byte_no = bitpos / 8;
    int bit_no = bitpos % 8;
    if (byte_no < len) {
        data[byte_no] &= ~(1 << bit_no);
        data[byte_no] |= (value & 1) << bit_no;
    }
}

inline void put_bits(uint8_t* data, int len, uint16_t bitpos, uint8_t size, uint32_t value) {
    for (int i = 0; i < size; i++) {
        put_bit(data, len, bitpos + i, (value >> i) & 1);
    }
}

bool needs_to_be_sent(uint8_t report_id) {
    uint8_t* report = reports[report_id];
    uint8_t* prev_report = prev_reports[report_id];
    uint8_t* relative = report_masks_relative[report_id];
    uint8_t* absolute = report_masks_absolute[report_id];

    for (int i = 0; i < report_sizes[report_id]; i++) {
        if ((report[i] & relative[i]) || ((report[i] & absolute[i]) != (prev_report[i] & absolute[i]))) {
            return true;
        }
    }
    return false;
}

void set_mapping_from_config() {
    std::unordered_set<uint32_t> layer_triggering_sticky_set;
    std::unordered_set<uint64_t> sticky_usage_set;
    std::unordered_set<uint64_t> screen_switching_usages_set;
    std::unordered_set<uint64_t> cycle_profile_usages_set;
    std::unordered_set<uint64_t> toggle_jiggle_usages_set;
    std::unordered_set<uint64_t> toggle_abs_smooth_usages_set;
    std::unordered_set<uint32_t> mapped;

    reverse_mapping.clear();
    activate_profile_usages.clear();

    for (auto const& mapping : config_mappings) {
        reverse_mapping[mapping.target_usage].push_back((map_source_t){
            .usage = mapping.source_usage,
            .scaling = mapping.scaling,
            .sticky = (mapping.flags & MAPPING_FLAG_STICKY) != 0,
            .layer = (mapping.layer < NLAYERS) ? mapping.layer : (uint8_t) 0,
        });
        if (mapping.layer == 0) {
            mapped.insert(mapping.source_usage);
        }
        if ((mapping.flags & MAPPING_FLAG_STICKY) != 0) {
            if ((mapping.target_usage & 0xFFFF0000) == LAYERS_USAGE_PAGE) {
                layer_triggering_sticky_set.insert(mapping.source_usage);
            } else {
                sticky_usage_set.insert(((uint64_t) mapping.layer << 32) | mapping.source_usage);
            }
        }
        if (mapping.target_usage == SWITCH_SCREEN_USAGE) {
            screen_switching_usages_set.insert(((uint64_t) mapping.layer << 32) | mapping.source_usage);
        }
        if (mapping.target_usage == CYCLE_PROFILE_USAGE) {
            cycle_profile_usages_set.insert(((uint64_t) mapping.layer << 32) | mapping.source_usage);
        }
        if (mapping.target_usage == TOGGLE_JIGGLE_USAGE) {
            toggle_jiggle_usages_set.insert(((uint64_t) mapping.layer << 32) | mapping.source_usage);
        }
        if (mapping.target_usage == TOGGLE_ABS_SMOOTH_USAGE) {
            toggle_abs_smooth_usages_set.insert(((uint64_t) mapping.layer << 32) | mapping.source_usage);
        }
        if (mapping.target_usage >= ACTIVATE_PROFILE_USAGE_BASE &&
            mapping.target_usage < ACTIVATE_PROFILE_USAGE_BASE + NPROFILES) {
            // Match the codebase's compound-literal idiom (see map_source_t
            // pushes above) rather than C++20 bare designated initializers,
            // because the firmware builds with -std=c++17.
            activate_profile_usages.push_back((activate_profile_binding_t){
                .layer_usage = ((uint64_t) mapping.layer << 32) | mapping.source_usage,
                .slot = (uint8_t) (mapping.target_usage - ACTIVATE_PROFILE_USAGE_BASE),
            });
        }
    }

    layer_triggering_stickies.assign(layer_triggering_sticky_set.begin(), layer_triggering_sticky_set.end());
    sticky_usages.assign(sticky_usage_set.begin(), sticky_usage_set.end());
    screen_switching_usages.assign(screen_switching_usages_set.begin(), screen_switching_usages_set.end());
    cycle_profile_usages.assign(cycle_profile_usages_set.begin(), cycle_profile_usages_set.end());
    toggle_jiggle_usages.assign(toggle_jiggle_usages_set.begin(), toggle_jiggle_usages_set.end());
    toggle_abs_smooth_usages.assign(toggle_abs_smooth_usages_set.begin(), toggle_abs_smooth_usages_set.end());

    if (unmapped_passthrough) {
        for (auto const& [usage, usage_def] : our_usages_flat) {
            if (!mapped.count(usage)) {
                reverse_mapping[usage].push_back((map_source_t){ .usage = usage });
            }
        }
    }
}

void screens_updated() {
    bounds_min_x = screens[0].x;
    bounds_max_x = screens[0].x + screens[0].w;
    bounds_min_y = screens[0].y;
    bounds_max_y = screens[0].y + screens[0].h;
    for (uint8_t i = 1; i < NSCREENS; i++) {
        bounds_min_x = std::min(bounds_min_x, (int64_t) screens[i].x);
        bounds_max_x = std::max(bounds_max_x, (int64_t) screens[i].x + screens[i].w);
        bounds_min_y = std::min(bounds_min_y, (int64_t) screens[i].y);
        bounds_max_y = std::max(bounds_max_y, (int64_t) screens[i].y + screens[i].h);
    }

    // Default to the first local screen (output=0), not the remote
    active_screen = 0;
    last_local_screen = -1;
    for (int i = 0; i < NSCREENS; i++) {
        if (screens.count(i) && screens[i].w > 0 && screens[i].output == 0) {
            if (last_local_screen == -1) {
                last_local_screen = i;
                active_screen = i;
            }
            break;
        }
    }
    cursor_x = screens[active_screen].x + screens[active_screen].w / 2;
    cursor_y = screens[active_screen].y + screens[active_screen].h / 2;
    abs_smooth_screen = -1;  // re-centre is a warp, not a sample to walk to
}

bool differ_on_absolute(const uint8_t* report1, const uint8_t* report2, uint8_t report_id) {
    uint8_t* absolute = report_masks_absolute[report_id];

    for (int i = 0; i < report_sizes[report_id]; i++) {
        if ((report1[i] & absolute[i]) != (report2[i] & absolute[i])) {
            return true;
        }
    }

    return false;
}

void aggregate_relative(uint8_t* prev_report, const uint8_t* report, uint8_t report_id) {
    for (auto const& [usage, usage_def] : our_usages[report_id]) {
        if (usage_def.is_relative) {
            int32_t val1 = get_bits(report, report_sizes[report_id], usage_def.bitpos, usage_def.size);
            if (usage_def.logical_minimum < 0) {
                if (val1 & (1 << (usage_def.size - 1))) {
                    val1 |= 0xFFFFFFFF << usage_def.size;
                }
            }
            if (val1) {
                int32_t val2 = get_bits(prev_report, report_sizes[report_id], usage_def.bitpos, usage_def.size);
                if (usage_def.logical_minimum < 0) {
                    if (val2 & (1 << (usage_def.size - 1))) {
                        val2 |= 0xFFFFFFFF << usage_def.size;
                    }
                }

                put_bits(prev_report, report_sizes[report_id], usage_def.bitpos, usage_def.size, val1 + val2);
            }
        }
    }
}

bool within_bounds(int64_t x, int64_t y, int8_t& active_screen) {
    active_screen = -1;
    for (uint8_t i = 0; i < NSCREENS; i++) {
        if (screens[i].w == 0) continue;  // skip unconfigured screens
        if (screens[i].x <= x &&
            x < screens[i].x + screens[i].w &&
            screens[i].y <= y &&
            y < screens[i].y + screens[i].h) {
            active_screen = i;
            break;
        }
    }

    return ((constraint_mode == ConstraintMode::VISIBLE && active_screen != -1) ||
            (constraint_mode == ConstraintMode::BOUNDING_BOX &&
                x >= bounds_min_x &&
                x < bounds_max_x &&
                y >= bounds_min_y &&
                y < bounds_max_y) ||
            (constraint_mode == ConstraintMode::NO_CONSTRAINT));
}

// Dead-band crossing helpers. When the cursor pushes toward a same-output
// neighbour that exists at the target coordinate on the push axis but is offset
// on the other axis (e.g. a shorter side monitor sitting lower than a tall main
// one), the within_bounds checks only slide the cursor along the current edge
// and it "sticks". These find the nearest such neighbour so the caller can snap
// the off-axis coordinate into it and let the crossing through. Restricted to
// the same output so they never bypass the remote's edge-resistance crossing.
static int8_t snap_target_screen_x(int64_t target_x, int64_t from_y, int8_t from_screen) {
    if (from_screen < 0) return -1;
    uint8_t want_output = screens[from_screen].output;
    int8_t best = -1;
    int64_t best_dist = INT64_MAX;
    for (uint8_t i = 0; i < NSCREENS; i++) {
        if ((int8_t) i == from_screen || screens[i].w == 0 || screens[i].output != want_output) continue;
        if (!(screens[i].x <= target_x && target_x < screens[i].x + screens[i].w)) continue;
        // Must be a genuine left/right neighbour: disjoint from the source on X.
        // A screen that merely overlaps our column (e.g. a tall main display
        // beside us whose X-range we're not in) is not a horizontal neighbour.
        if (!(screens[i].x + screens[i].w <= screens[from_screen].x ||
              screens[i].x >= screens[from_screen].x + screens[from_screen].w)) continue;
        int64_t lo = screens[i].y;
        int64_t hi = screens[i].y + screens[i].h - 1;
        int64_t dist = (from_y < lo) ? (lo - from_y) : (from_y > hi ? from_y - hi : 0);
        if (dist < best_dist) {
            best_dist = dist;
            best = (int8_t) i;
        }
    }
    return best;
}
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
int main() {
    mutex_init(&their_usages_mutex);
    extra_init();
    forwarder_serial_init();
    parse_our_descriptor();
    load_config();
    board_init();
    tusb_init();

    // Force the host to re-enumerate on every boot. After an SWD flash the core
    // restarts but the USB line state can persist, so macOS keeps the stale
    // connection and the HID interface comes up half-dead until the cables are
    // power-cycled. An explicit detach/attach makes the host drop and re-enumerate
    // the device cleanly, so a flash no longer needs an unplug.
    tud_disconnect();
    sleep_ms(100);
    tud_connect();

    tud_sof_isr_set(sof_handler);

    next_print = time_us_64() + 1000000;
    last_input_per_output_us[0] = time_us_64();
    last_input_per_output_us[1] = time_us_64();

    static bool wakeup_sent = false;

    while (true) {
        if (read_report()) {
            process_mapping(get_and_clear_tick_pending());
        }
        tud_task();
        if (tud_hid_ready()) {
            if (get_and_clear_tick_pending()) {
                process_mapping(true);
            }
            send_report();
        } else if (tud_suspended() && or_items > 0) {
            // The local USB host is asleep. Drain reports bound for the remote
            // (output 1) over serial so it still gets jiggled, without disturbing
            // the local machine. Only issue a remote wakeup for a report actually
            // destined for the local host (output 0) - maybe_jiggle() won't queue
            // an output-0 report while suspended, so an output-0 report at the
            // head is genuine user input, where wake-on-input is wanted.
            uint8_t head_idx = outgoing_reports[or_head][0];
            uint8_t head_output = (screens.count(head_idx) && screens[head_idx].output != 0) ? 1 : 0;
            if (head_output == 1) {
                send_report();
            } else if (!wakeup_sent) {
                tud_remote_wakeup();
                wakeup_sent = true;
            }
        }
        if (!tud_suspended()) {
            wakeup_sent = false;
        }

        if (their_descriptor_updated) {
            update_their_descriptor_derivates();
            their_descriptor_updated = false;
        }
        if (need_to_persist_config) {
            persist_config();
            need_to_persist_config = false;
        }

        maybe_jiggle();
        service_blink();
        service_type_text();
        service_gestures();

        print_stats();
    }

    return 0;
}

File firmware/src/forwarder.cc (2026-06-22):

#include <bsp/board.h>
#include <tusb.h>

#include "hardware/gpio.h"
#include "hardware/watchdog.h"
#include "pico/stdlib.h"

#include "our_descriptor.h"
#include "serial.h"

#define FORWARDER_UART uart1
#define FORWARDER_RX_PIN 9

bool led_state = false;

// Wake-from-sleep recovery. The second computer's USB bus only suspends when
// that machine sleeps (during normal use the host keeps the bus active). After
// a long sleep the device can come back enumerated-but-dead on the host: the
// bus resumes but the host's HID stack for us is stale, so no forwarded input
// reaches it until a physical replug. Force a clean re-enumeration on resume,
// mirroring the boot-time detach/attach in remapper.cc that fixed the same
// "half-dead until replug" symptom on Pico A. Gate on suspend duration so only
// a genuine sleep (not a hypothetical brief OS suspend) triggers the bounce.
static const uint64_t REENUM_SUSPEND_THRESHOLD_US = 5000000;  // 5 s
static volatile uint64_t suspend_started_us = 0;
static volatile uint64_t last_suspend_duration_us = 0;
static volatile bool resume_pending = false;

// While the host is asleep, retry the remote wakeup on this interval instead of
// latching after a single attempt. A Mac in deep sleep often ignores the first
// device-initiated wakeup; latching meant a morning mouse-nudge could never wake
// the second computer until a power cycle. Only retried when Pico A is actually
// sending us frames (i.e. the user is trying to drive the remote).
static const uint64_t WAKEUP_RETRY_INTERVAL_US = 1000000;  // 1 s
static uint64_t last_wakeup_us = 0;

// Stuck-while-awake auto-recovery. The resume bounce above only fires on a clean
// tud_resume_cb(); a VBUS brown-out during the second computer's sleep transition
// can leave us enumerated-but-dead with no suspend/resume callback at all. If
// Pico A is feeding us frames (so the remote is in use) but the HID endpoint
// stays undeliverable while the bus is NOT suspended, escalate: first a
// re-enumeration bounce, then a cold watchdog reboot - the automatic equivalent
// of the manual power cycle that was previously the only fix.
static const uint64_t RECENT_RX_WINDOW_US = 1500000;  // frames seen this recently => remote in use
static const uint64_t RECOVERY_STEP_US = 3000000;     // 3 s stuck before each escalation
static uint64_t last_serial_rx_us = 0;
static uint64_t undeliverable_since_us = 0;
static bool bounce_tried = false;

// Only relay reports whose ID this device actually advertises. A garbled serial
// frame, or a Pico A running newer firmware with a report ID this forwarder's
// descriptor doesn't declare, would otherwise be passed to tud_hid_report() and
// can stall the HID interface on the remote host - killing all forwarded input.
static bool known_report_id(uint8_t report_id) {
    return report_id == REPORT_ID_MOUSE ||
           report_id == REPORT_ID_KEYBOARD ||
           report_id == REPORT_ID_CONSUMER ||
           report_id == REPORT_ID_RELATIVE;
}

void serial_callback(const uint8_t* data, uint16_t len) {
    // Any frame from Pico A means the remote is being driven. Stamp it so the
    // main-loop recovery knows delivery is wanted right now.
    last_serial_rx_us = time_us_64();

    if (tud_suspended()) {
        if (last_serial_rx_us - last_wakeup_us >= WAKEUP_RETRY_INTERVAL_US) {
            tud_remote_wakeup();
            last_wakeup_us = last_serial_rx_us;
        }
        return;
    }
    if (len < 2 || !known_report_id(data[0])) {
        return;
    }
    if (!tud_hid_ready()) {
        // Bus is up but the endpoint won't take a report; drop it and let the
        // main loop's stuck-detector escalate to a bounce/reboot.
        return;
    }
    tud_hid_report(data[0], data + 1, len - 1);
    board_led_write(led_state);
    led_state = !led_state;
}

void forwarder_serial_init() {
    uart_init(FORWARDER_UART, FORWARDER_BAUDRATE);
    uart_set_translate_crlf(FORWARDER_UART, false);
    gpio_set_function(FORWARDER_RX_PIN, GPIO_FUNC_UART);
}

// Invoked from tud_task() (not ISR) when the USB bus suspends/resumes, so it is
// safe to read the clock and set flags here. The heavy re-enumeration work is
// deferred to the main loop rather than done in the callback.
void tud_suspend_cb(bool remote_wakeup_en) {
    (void) remote_wakeup_en;
    suspend_started_us = time_us_64();
}

void tud_resume_cb() {
    last_suspend_duration_us = time_us_64() - suspend_started_us;
    resume_pending = true;
}

// Escalating recovery when remote input is being delivered to us but the host
// endpoint is stuck. Returns nothing; reboots the device if the bounce fails.
static void service_stuck_recovery() {
    uint64_t now = time_us_64();
    bool remote_in_use = (now - last_serial_rx_us) < RECENT_RX_WINDOW_US;

    if (tud_suspended() || !remote_in_use || tud_hid_ready()) {
        undeliverable_since_us = 0;
        bounce_tried = false;
        return;
    }

    if (undeliverable_since_us == 0) {
        undeliverable_since_us = now;
        return;
    }
    if (now - undeliverable_since_us < RECOVERY_STEP_US) {
        return;
    }

    if (!bounce_tried) {
        tud_disconnect();
        sleep_ms(100);
        tud_connect();
        bounce_tried = true;
        undeliverable_since_us = now;  // give the re-enumeration a full window
    } else {
        // Bounce didn't restore delivery: cold-restart into the normal image.
        watchdog_reboot(0, 0, 0);
    }
}

int main() {
    board_init();
    tusb_init();

    // Force the host to re-enumerate on boot, same as remapper.cc. A warm reboot
    // (e.g. VBUS browning out as the second computer enters/leaves deep sleep)
    // can leave the USB line state asserted, so the host keeps the stale
    // connection and the HID interface comes up half-dead until a replug. An
    // explicit detach/attach makes the host drop and re-enumerate us cleanly.
    tud_disconnect();
    sleep_ms(100);
    tud_connect();

    forwarder_serial_init();

    while (true) {
        serial_read(serial_callback, FORWARDER_UART);
        tud_task();
        if (resume_pending) {
            resume_pending = false;
            // Only bounce after a real sleep, not a brief suspend.
            if (last_suspend_duration_us > REENUM_SUSPEND_THRESHOLD_US) {
                tud_disconnect();
                sleep_ms(100);
                tud_connect();
            }
        }
        service_stuck_recovery();
    }

    return 0;
}

void tud_hid_set_report_cb(uint8_t itf, uint8_t report_id, hid_report_type_t report_type, uint8_t const* buffer, uint16_t bufsize) {
}

uint16_t tud_hid_get_report_cb(uint8_t itf, uint8_t report_id, hid_report_type_t report_type, uint8_t* buffer, uint16_t reqlen) {
    return 0;
}

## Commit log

2026-06-22 feat: add support for pico2 and multi-monitor layouts
    [BOM-compact.csv, BOM-smd.csv, BOM-tht.csv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]
2026-10-15 Relayout config to live macOS arrangement; add relayout.py
    - Laptop moved to 2056x1329@(-2056,676) in macOS; stale 1728x1117@602 layout made left crossings below LG y=1329 wrap
    - relayout.py rewrites screens/coord_scale/sensitivity/edge_resistance from a display list, keeps mappings and drag gain
2026-10-28 Relayout config for two side-by-side 5K LGs (clamshell)
    - Displays: 3360x1890@(0,0) main, 3360x1890@(-3360,0); remote below both
    - CLAUDE.md runbook examples updated to the new layout
2026-10-28 Place remote under the right 5K only
    - relayout.py: --remote-under N puts the remote below one display, keeping remote pointer speed
    - Crossing down from the right 5K now lands directly below instead of offset right
2026-10-29 Relayout config for 5K LGs at 3840x2160 logical
2026-11-01 Relayout for 5Ks back at 3360x1890; add relayout.py --keep-sensitivity
    - Keeps physical pointer speed (sensitivity 2474) across a scaled-resolution change
    - Compare stored int coord_scale so re-running on an unchanged layout is a no-op
2026-11-03 Put host on the seam before crossing and track last screen per output
    - Crossing via the remote now moves the host to the new local display
    - Absolute report at the seam means the fixed burst always reaches it
    - Drop speed-based burst sizing
2026-11-10 Stop via-remote crossing burst overshooting the target display
    - macOS pins the pointer at the seam when a move ends beyond every display
    - 2 counts per px of landing distance overshot when the host was parked on the seam (4 captured failures)
    - Burst now aims a third into the target from the parked position at 0.75 px per count
